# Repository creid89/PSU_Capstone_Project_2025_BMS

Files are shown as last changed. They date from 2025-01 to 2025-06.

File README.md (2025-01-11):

2025 PSU Senior Capstone Project

Battery Management System for PSU Student EPL (Engineering Prototyping Lab)

Members:
Cuauhtemoc Gomez Angeles <cuauh@pdx.edu>
Cody Reid <codreid@pdx.edu>
Fernando Custodio Calderon <fernan27@pdx.edu>
Tyler Tran <tytran@pdx.edu>
Daniel Anishchenko <danish2@pdx.edu>

Inudstry Sponsor: 
Edward Ivory <edivory@pdx.edu>

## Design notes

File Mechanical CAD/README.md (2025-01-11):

This folder contains the mechanical design files for the project. These files are created and maintained using CAD (Computer-Aided Design) software and include models, assemblies, drawings, and related documentation.

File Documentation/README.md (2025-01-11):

This folder contains all project-related documentation, including guides, reports, reference materials, and other supporting files. The purpose of this folder is to provide detailed information about the project, its design, implementation, and usage.

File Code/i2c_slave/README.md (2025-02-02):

Folder to store revisions of i2c_init.c and Cmake files

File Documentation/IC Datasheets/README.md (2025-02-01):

Datasheets for ICs to potentially integrate for current sensing and ADC

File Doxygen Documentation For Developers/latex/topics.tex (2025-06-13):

\doxysection{Topics}
Here is a list of all topics with brief descriptions\+:\begin{DoxyCompactList}
\item \contentsline{section}{EEPROM Storage Addresses}{\pageref{group___e_e_p_r_o_m___storage}}{}
\item \contentsline{section}{INA219 Sensor Instances}{\pageref{group___i_n_a219___instances}}{}
\item \contentsline{section}{Major System Control Flags}{\pageref{group___system___flags}}{}
\item \contentsline{section}{Timer and Configuration Flags}{\pageref{group___timer___flags}}{}
\item \contentsline{section}{INA219 and BQ25730 Variables}{\pageref{group___i_n_a___b_q___variables}}{}
\item \contentsline{section}{LTC2943 Scaling Factors and Constants}{\pageref{group___l_t_c2943___constants}}{}
\item \contentsline{section}{Cell Balancing Variables}{\pageref{group___balancer___variables}}{}
\item \contentsline{section}{System Return Variables}{\pageref{group___system___returns}}{}
\item \contentsline{section}{LTC2943 Configuration Parameters}{\pageref{group___l_t_c2943___config}}{}
\item \contentsline{section}{BQ25730 Charger Configuration Parameters}{\pageref{group___b_q25730___config}}{}
\item \contentsline{section}{Timing Control Variables}{\pageref{group___timing___variables}}{}
\item \contentsline{section}{I2C Communication Setup}{\pageref{group___i2_c___communication}}{}
\item \contentsline{section}{I2C Device Addresses}{\pageref{group___device___addresses}}{}
\item \contentsline{section}{LTC2943 Register Addresses}{\pageref{group___l_t_c2943___registers}}{}
\item \contentsline{section}{BQ25730 Register Addresses}{\pageref{group___b_q25730___registers}}{}
\item \contentsline{section}{LTC2943 Fuel Gauge Functions}{\pageref{group___l_t_c2943___functions}}{}
\item \contentsline{section}{BQ25730 Battery Charger Functions}{\pageref{group___b_q25730___functions}}{}
\end{DoxyCompactList}

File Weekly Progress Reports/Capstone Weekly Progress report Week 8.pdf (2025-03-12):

## Progress Report - Week 8 | Mar. 1 - Mar. 8, 2025

Group 6:
Cody Reid
Cuauhtemoc Gomez Angeles
Daniel Anishchenko
Tyler Tran
Fernando Custodio Calderon

Progress Discussion:
- Issues with actuating N-Channel Mosfet using Microcontroller’s GPIO Pins still persist for Cell Balancer.
- Transfer Switch in development; switching parameters are semi-operational. Currently on the 4th iteration of Transfer Switch.
- STM32 Peripheral mode prototyping successfully implemented
- STM32 reading from Qty. (1) INA260 and receiving messages over UART both on a timer interrupt basis.

Discussion Notes:
- New transfer switch design proposed by advisor, addition of nmos with the ideal diode will ensure switching using GPIO
- Don’t use linear supply
- start sending data back to the master system
- Investigations needed for battery chip to replace one of two load switches
- Found new battery chip: https://www.ti.com/product/BQ25713

Tasks at hand:
- integrate all 4 INAs
- Work on 4th iteration of advisor proposed load switch design
- Debug issues with GPIO controlled NMOS for battery balancer
- use a power supply and resistors to simulate charging
- generate a cell balancing algorithm
- Test charging behaviors of the 18650 Sodium cells
- Investigate BQ25713 for use in wall-end load switch

General Notes From Meeting:

Load Switch Operation
- M3 and M4 are load switches in a high-side configuration.
- To power the load, both transistors must be on.
- If only M4 is on, current still flows to the load through the body diode of M3, causing a 0.7V drop.
- The body diode is an intrinsic part of the MOSFET, like D1 and D2 in the circuit.

Battery Charging and Voltage Regulation

Connecting a 20V charger to a 12V battery:
- Current flows from the charger to the battery.
- The amount of current depends on how the charger regulates its voltage.

Understanding Current Flow:
- If the external power supply is 12V and the battery is 12V, little to no current flows.
- Increasing the charger voltage slightly (e.g., 12.1V) causes some current to flow, depending on internal resistances (battery, wiring, etc.).
- To control current, the charger uses a constant current supply, which regulates voltage to maintain a set charging current (e.g., 1A, 5A, 10A).

Charging Phases:
1. Constant Current Mode:
- The charger increases voltage until the target charging current is reached (e.g., 5A).
- The battery voltage gradually rises as it charges.
2. Constant Voltage Mode:
- Once the battery reaches its float voltage (e.g., 12.5V), the charger stops increasing voltage.
- Current gradually decreases as the battery approaches full charge.
- At full charge, current stabilizes at a low float value.

Charge Graph Behavior:
- Current rises sharply in constant current mode.
- As voltage reaches float level, current tapers off.
- The battery remains in a float state, maintaining its charge.

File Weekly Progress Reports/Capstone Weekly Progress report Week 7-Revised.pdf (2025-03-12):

## Progress Report - Week 7 | Feb. 22 - Mar. 1, 2025

Group 6:
Cody Reid
Cuauhtemoc Gomez Angeles
Daniel Anishchenko
Tyler Tran
Fernando Custodio Calderon

Progress Discussion:
- The Cell Balancing Circuit is operational, currently facing actuating N-Channel Mosfet to activate with the Microcontroller’s GPIO Pins.
- Transfer Switch in development; switching parameters are semi-operational. Currently on the 3rd iteration of Transfer Switch.
- Programming Notes:
○

Discussion Notes:
- Need to get the transfer switch working. Prototype is at hand, but no components to test at the moment.
- The load switch will be controlled by the transfer switch.
- Have a capacitor that when power is unplugged, and cap reaches zero, load switch is kicked from external control to load.
- When external power is plugged in, voltages go to both the load AND the batteries
- Sensor Transition:
- Moved from using the INA219 and ADS1115 to four INA260 sensors.
- The ADS1115 was inaccurate and could not reliably measure the voltages seen in a 4S battery pack.
- The INA260 provides all necessary measurements (voltage, current, and power) in a single package, simplifying the design.
- Microcontroller Update:
- Switched from the RP2350 to an STM32.
- Currently implementing UART communication between a controller and the STM32 for data transmission.
- Load Switching: Implementing an ideal diode to efficiently manage switching the load on and off from the battery supply.
- Power Management Discussion: Evaluating the use of a Charger IC to manage power when the system is plugged into an external source (e.g., wall outlet).

Tasks at hand:
- STM32 Peripheral mode prototyping
- Test and integrate transfer switch w/ balancing circuit.

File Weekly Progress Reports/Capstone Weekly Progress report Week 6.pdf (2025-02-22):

# Progress Report - Week 6 | Feb. 15 - 22, 2025

Group 6:
Cody Reid
Cuauhtemoc Gomez Angeles
Daniel Anishchenko
Tyler Tran
Fernando Custodio Calderon

Notes:
- We will use a thermistor for thermal regulation, ADC has extra pins so maybe multiple thermistors?
- Transfer switches; need to figure out if we want to use pmos or nmos. Leaning towards Pmos, explored BJT options
- Breakthrough made with passive cell balancing circuit, will need to integrate with transfer switch design
- Physical testing of transfer design needed, will be started within this week - in progress
- Transfer switch difficulties 2/18, MOSFETS burned, will need replacements on 2/19
- Test program will need to be made this week that allows transfer switch toggling using rp2350
- We managed to explode an INA219 module. Device fried (no seriously, RIP shunt resistor)
- Issues being faced with sensors INA219 - Mainly with getting it to handshake consistently
- Team managed to connect to the ADC and the Current meter, still working on dialing in calculations for the voltage and figuring out reference voltage best practices
- Battery housing being reprinted and will be picked up on Wednesday
- Wednesday Feb. 19 @4pm in person meeting w/ Andrew Greenburg at EPL
- Looking for 19V adc due to our current one not being able to handle the voltage
- Consider the use of the ina226 due to a higher power rating
- Use shunt resistors to mitigate power
- Consider the use of Ideal diodes for the transfer switch

Tasks at hand:
- Project Proposal - Still need legal part for IP As of Feb 15 - Will need to start giving pushback to speedup process
- Sensor Validation
- RP2350 Peripheral mode prototyping
- Passive battery balancing design
- Test and integrate transfer switch w/ balancing circuit
- Battery housing (3D printed) - DELAYED DUE TO SNOW - need to pickup

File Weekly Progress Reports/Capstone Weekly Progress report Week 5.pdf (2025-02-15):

# Progress Report - Week 5 | Feb. 8 - 15, 2025

Group 6:
Cody Reid
Cuauhtemoc Gomez Angeles
Daniel Anishchenko
Tyler Tran
Fernando Custodio Calderon

Notes:
- Progress slightly hampered this week due to midterms
- Wednesday Feb. 19 @4pm in person meeting w/ Andrew Greenburg at EPL
- Battery housing printed on Feb 12, however a reprint is needed due to quality issues. As of Feb 13, snow day has delayed pick up of 3d model
- Progress made in balancing circuit design and development of semi working prototype will be in progress from this Feb 15 onward to Feb 22.
- Current sensor module on both sides, we want sensing of both I/O
- Overvoltage goes to charge control voltage switch
- Undervoltage goes to control power output switch
- power output stage -> output switch
- Transfer switch - > Bypass Switch

Tasks at hand:

- Project Proposal - Still need legal part for IP As of Feb 15
- Sensor integration with I2C bus
- Sodium ion battery tests with balancing circuit
- Test and integrate transfer switch w/ balancing circuit
- Battery housing (3D printed) - DELAYED DUE TO SNOW

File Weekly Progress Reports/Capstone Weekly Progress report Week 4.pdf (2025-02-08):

# Progress Report - Week 4 | Feb. 1 - 8, 2025

Group 6:
Cody Reid
Cuauhtemoc Gomez Angeles
Daniel Anishchenko
Tyler Tran
Fernando Custodio Calderon

Notes:
- Difficulty have been encountered with RP2350 connections, we might decide to switch over to the rp2040
- We decided not to use ADC due to issues we found during experimentation with the board
- Met with advisor and sponsor on Feb 03 to discuss IP and the project proposal, in short, Ed will own the IP but we are free to use the design
- We will work on revising our level 1 block diagram
- Progress made on transfer switch design with this article. (https://www.powersystemsdesign.com/articles/application-of-power-mosfet-in-battery-management-charge-discharge-system/145/19032) Purpose of the transfer switch is to toggle between 1s, 2s, 3s, 4s.
- We will also switch to C++ on the arduino IDE - this decision is accepted by our advisor and sponsor
- We will schedule a meeting with Ed and/or staff of the epl to work with the PCB mill and laser cutter
- We will now use a 24V power supply instead of 12V

Tasks at hand:

- Project Proposal - Submit by Saturday 2/8 11:59 UPDATE: Need Legal IP statement from Andrew to be pasted
- I2C bus implementation
- Hardware and battery tests
- Transfer switch mosfet design
- Battery housing (3D printed)

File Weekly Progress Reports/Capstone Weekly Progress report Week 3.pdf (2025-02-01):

# Progress Report - Week 3 | Jan. 24 - Feb. 1, 2025

Group 6:
Cody Reid
Cuauhtemoc Gomez Angeles
Daniel Anishchenko
Tyler Tran
Fernando Custodio Calderon

Notes:
- Buy Power Supply (https://www.amazon.com/Adapter-Converter-Transformer-100-240V-Security/dp/B0BX2MYCV9)
- Get batteries from Ed
- Test functionality rp2350
- Validate hardware
- See if our battery data is in line with real world usage
- I2C slave config
- For architecture, choose gpio sensor package, battery management chip, or IO breakout/expansion board - will need to decide on this by the end of this week 2/1 -Update: We will do a component by component solution for this
- Rtas integration - decide after we choose architecture *Andrew suggests NOT to use it due to the added complexity
- straight C or circuitPython is recommended by Andrew
- Schedule a meeting to go over proposal on Friday 2pm Online
- Next week - Faculty Advisor meeting moved to Friday @3pm
- For development keep using ARDUINO To just get things to work and then eventually ditch Arduino and then go straight C. If we start with straight C, try to find libraries then for I 2C communication and all that kind of stuff.
- Faculty advisor needs to give input
So now is the time to share that with ED and with Andrew and they'll give comments and proposals and by the third we need both of their signatures saying that this is good to go
- 3 high-level architectures, The first one we just used the RP 2350 we might use a couple of its analog pins But for the most part we'd be using a management IC that we would then kind of tune to make it happy with sodium ion
- Second option
was we use some sort of IO expansion board because of the RP 2350 doesn't have a lot of analog pins And we'll basically kind of design our own BMS and software using that
- 3rd would be Maybe using some sort of IO expansion board Yeah, like a IO expansion board or something another sensor package or we could try and do it all Through the pins and sensors
- SUGGESTION from Andrew , use I2C and ADC, ADC that can handle the voltage of a 4 s-pack so up to 12 volts,
And so that way you don't have you don't have to worry about the crappy Picos analog and also shifting the analog voltage and or having dividers or anything that's like that might be able to get small I 2C package that can handle the voltage and then just you can just wire it straight into All 4 channels,(4 channels , cell 1,2,3,4)
- Andrew got scheduled to go to California Wednesday to Thursday he will try and call in but might not be able to make it wednesday of next week
- So we should schedule a different time
- Andrew wants us to to get 3S using a 12V battery for LI ION cuz alot of things will use that (3 should be a HIGH SHOULD)
- Ed wants the IP
He's thinking about selling it
We Might want to negotiate with him while andrew is there, and should be in the project proposal
●
- chat with Ed about setting up maybe like an accounting System or something for all the EPL stuff that we're gonna be grabbing
- Use Google spreadsheet for tracking the EPL stuff we take
- Power Supply Adapter (https://www.amazon.com/Adapter-Converter-Transformer-100-240V-Security/dp/B0BX2MYCV9)
- Next week 2:30pm Tuesday zoom meeting
- Next week 3pm Monday in person
- Adafruit ADS7830 8-channel w/ I2C - Add to buy list
- Instead of utilizing a BMS, we will make our own using a component by component solution

Tasks at hand:

- Project Proposal - will finish rough draft on Saturday, 1/25 and reviewed by our faculty advisor + sponsor to be submitted on Monday 2/3 for the final draft - UPDATE no feedback from Advisor & Sponsor as of Feb. 1st.
- Research research research Part 2- need to research more on the RP2350, This task will be for the whole team

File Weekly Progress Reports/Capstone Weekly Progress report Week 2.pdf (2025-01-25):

# Progress Report - Week 2 | Jan. 17-24, 2025

Group 6:
Cody Reid
Cuauhtemoc Gomez Angeles
Daniel Anishchenko
Tyler Tran
Fernando Custodio Calderon

Notes:

- Meeting with Ed on Wednesday 4:00-4:45pm
- Met after meeting with Ed to work on Project Proposal
- Battery data (found on google drive) has been updated with new data on Nimh
- Sodium ion will now be moved to should instead of must. This decision is confirmed by Ed, our sponsor. Edit: as of Friday January 24, we now have the decision canonized by our faculty advisor.
- Plan is to meet on Saturday to finalize the rough draft of the project proposal
- Andrew Greenburg is now assigned to us as our faculty advisor in 1/24
- RP2040 has arrived and testing and experimentation will commence as soon as possible
- We will explore the possibility of cannibalizing the Raspberry Pi Pico 2’s SOM for our own circuit
- Something that we have to consider in this project will be battery safety, which will be apparent when managing the Lithium batteries.
- In the meeting with our faculty advisor we have decided to assign a communications lead and team lead. Cody, who is our communication lead, will be in charge of anything that relates to the communication between the team and the sponsor. Daniel will be our team lead, who will ensure team organization and synergy. He will report any issues to our Faculty Advisor.
- We will also now meet with our faculty advisor on Wednesdays at 3:00 pm PST for a short 15-30 minute check-in. Make sure project logs/ progress reports are ready by then.

Tasks at hand:

- Project Proposal - will finish rough draft on Saturday, 1/25 and reviewed by our faculty advisor + sponsor to be submitted on Monday 1/26 for the final draft
- PDS - Worked slightly on this
- Research research research - need to research more on charge balance specifically passive balancing which is what Ed recommends. Also more research will have to be done for the system architecture.

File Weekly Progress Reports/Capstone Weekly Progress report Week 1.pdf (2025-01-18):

# Progress Report - Week 1 | Jan. 11-17, 2025

Group 6:
Cody Reid
Cuauhtemoc Gomez Angeles
Daniel Anishchenko
Tyler Tran
Fernando Custodio Calderon

Notes:

- Decided to meet twice a week:
- Wednesdays @ 1:45 for approximately 15 min
- Saturday 10am or 11am to 1pm
- Decided to use only Github for everything instead of using both google drive and git to simplify matters
- Met with Industry sponsor on Jan. 13, in summary we need to design a relatively inexpensive board that will be mainly for the Sodium ion 18650, the three others will come later (See Jan 13 meeting notes for more details)
- Chose a few Power management IC’s to work with, namely the TI BQ21061, TI BQ26221, and the Seiko S-8225A
- Need more material on Nickel Polymer batteries

Tasks at hand:

- Team Contract - Finish by the end of Saturday. Jan 18
- PDS - Start on this as soon as possible but might need to meet with Ed again
- Research research research - need to get a clearer picture of what we are going to create: need to figure out battery management system, battery charging system, and quirks with each given battery type

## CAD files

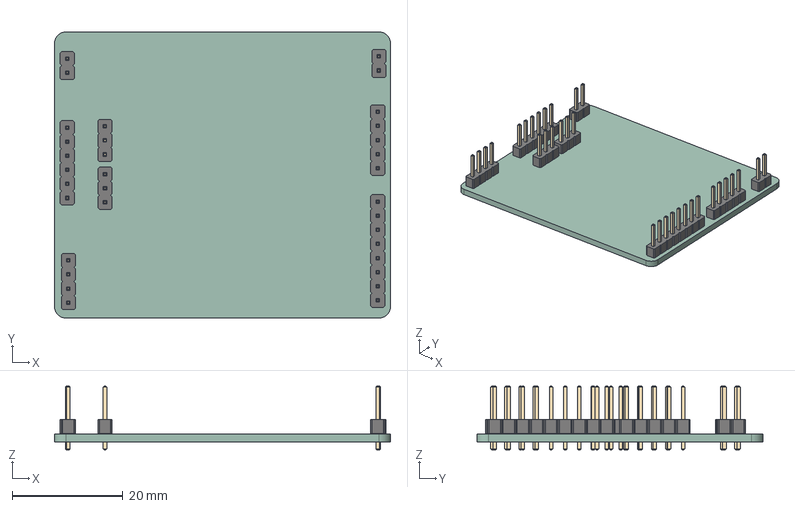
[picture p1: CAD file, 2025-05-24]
Board/Breakout/Breakout Board for BMS.step
60.6 x 51.6 x 11.5 mm
PinHeader_1x03_P2.54mm_Vertical x 2
PinHeader_1x04_P2.54mm_Vertical
PinHeader_1x02_P2.54mm_Vertical x 2
PinHeader_1x08_P2.54mm_Vertical
PinHeader_1x05_P2.54mm_Vertical
PinHeader_1x06_P2.54mm_Vertical
Breakout Board for BMS_PCB

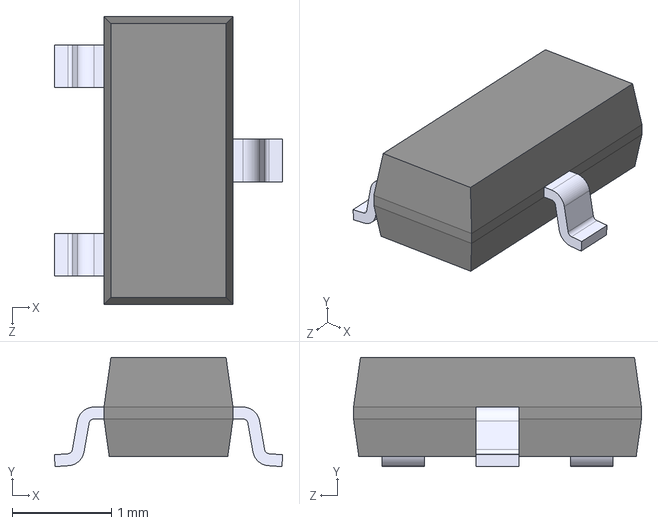
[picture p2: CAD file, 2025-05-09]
Board/KiCAD/Components/2N7002_215/2N7002P_215.step
2.30 x 1.10 x 2.90 mm

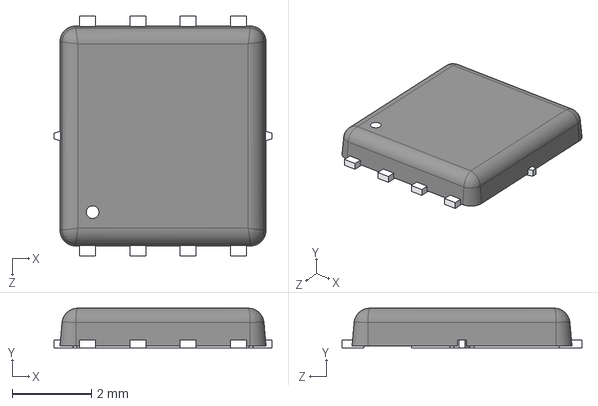
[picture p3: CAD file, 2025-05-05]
Board/KiCAD/Components/AON6407/AON6407.step
5.50 x 1.00 x 6.05 mm

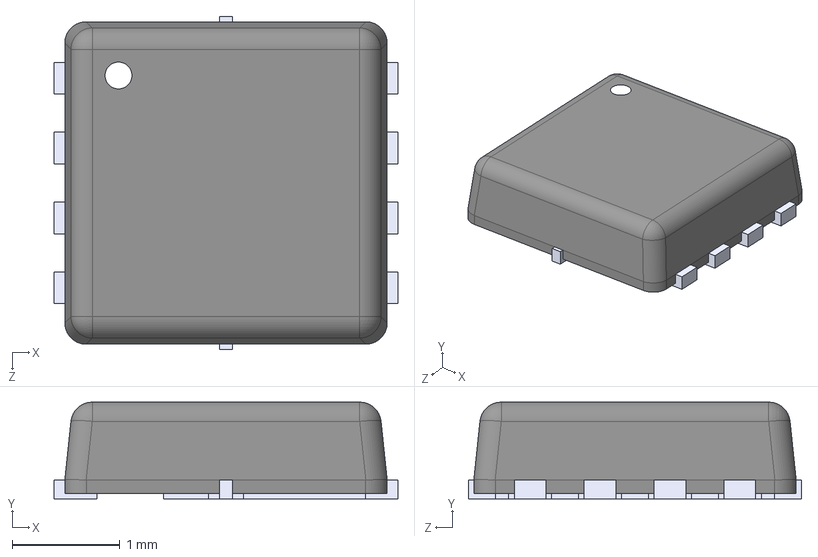
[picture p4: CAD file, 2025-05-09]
Board/KiCAD/Components/AON7407/AON7407.step
3.20 x 0.9 x 3.10 mm

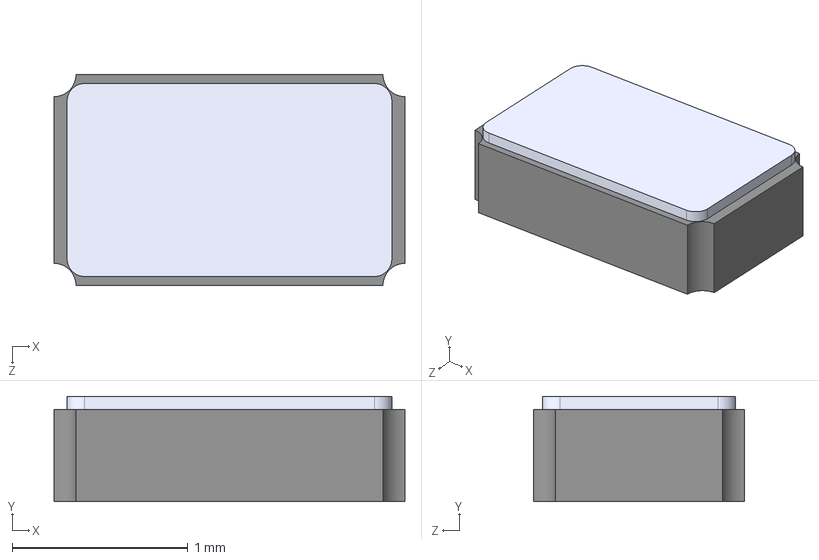
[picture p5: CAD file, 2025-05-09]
Board/KiCAD/Components/CM8V-T1A-32.768KHZ/CM8V-T1A-32.768KHZ-12.5PF-20PPM-TA-QA.step
2.00 x 0.6 x 1.20 mm

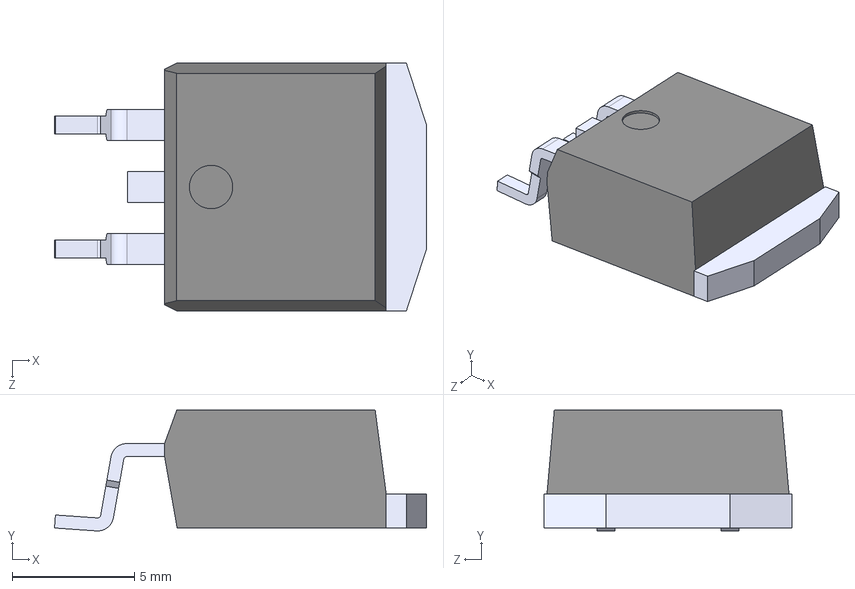
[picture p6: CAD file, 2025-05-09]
Board/KiCAD/Components/IRF9540NSTRLPBF/IRF9540NSTRLPBF.step
15.2 x 4.95 x 10.2 mm

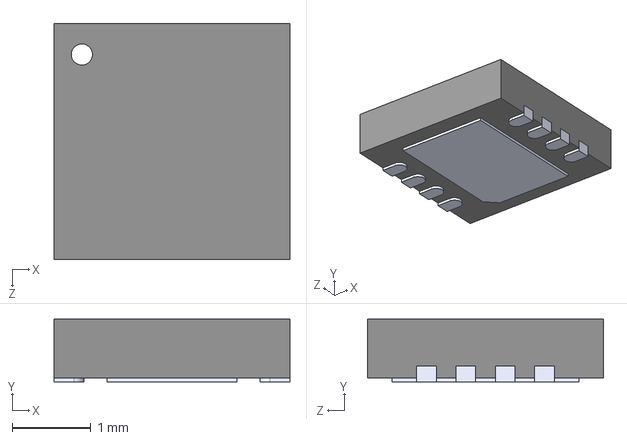
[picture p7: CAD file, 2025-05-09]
Board/KiCAD/Components/LTC2943/LTC2943CDD_PBF.step
3.00 x 0.8 x 3.00 mm

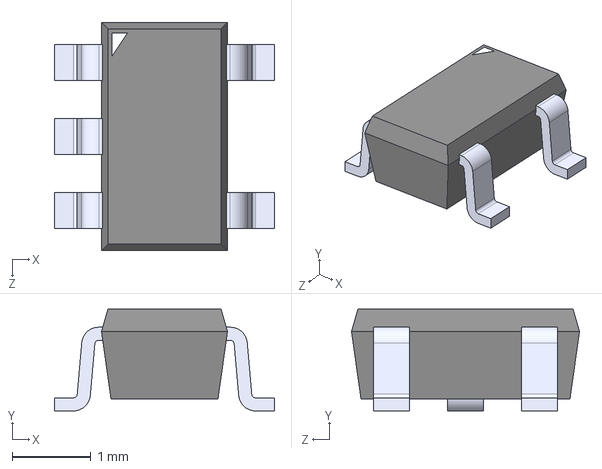
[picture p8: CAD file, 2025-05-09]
Board/KiCAD/Components/RT9193-32GB/RT9193-33GB.step
2.79 x 1.30 x 2.90 mm

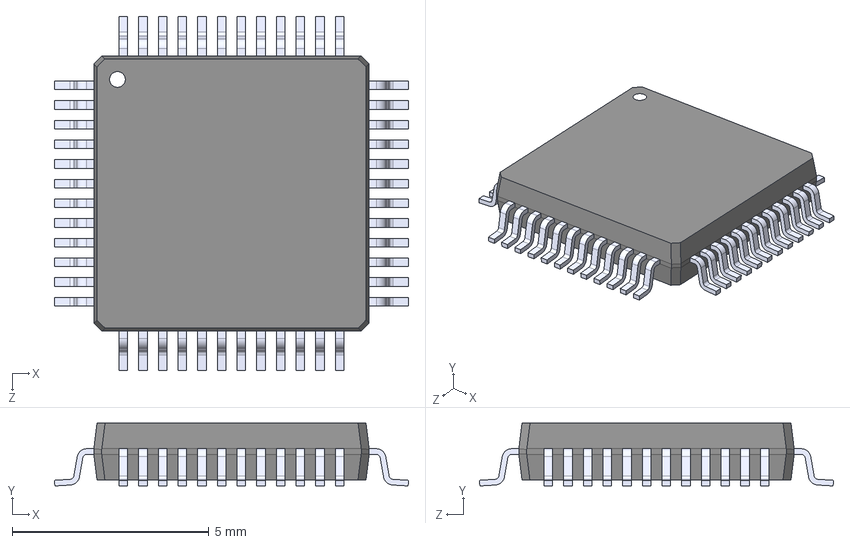
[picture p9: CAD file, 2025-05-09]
Board/KiCAD/Components/STM32F103C8T6/STM32F103C8T6.step
9.00 x 1.60 x 9.00 mm

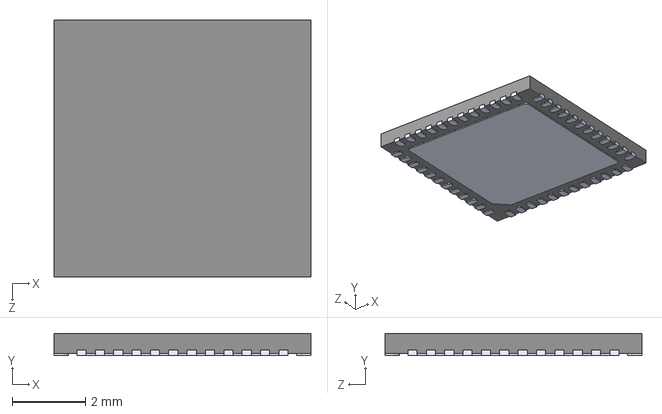
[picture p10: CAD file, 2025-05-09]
Board/KiCAD/Components/STM32F411CEU6/STM32F411CEU6.step
7.00 x 0.6 x 7.00 mm

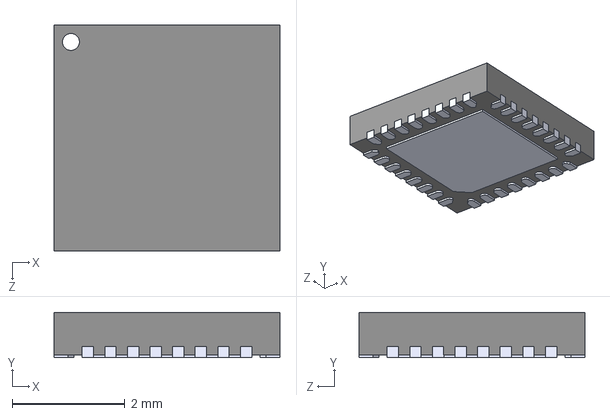
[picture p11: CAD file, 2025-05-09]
Board/KiCAD/Components/BQ25730RSNR/BQ25730RSNR.step
4.00 x 0.8 x 4.00 mm

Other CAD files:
Board/KiCAD/Components/AON7408/AON7408.step
Board/Breakout/Breakout Board for BMS.stl

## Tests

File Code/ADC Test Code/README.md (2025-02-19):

Folder to store code for testing the ADC

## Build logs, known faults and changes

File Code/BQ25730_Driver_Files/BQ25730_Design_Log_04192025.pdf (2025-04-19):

# BQ25730 Driver Development Log

### Developer

Cody Reid

### Project

Universal Battery Management System (BMS) Controller

### Component

BQ25730 Buck-Boost Battery Charger Controller

### Date Range

Ongoing (Latest Update: April 19, 2025)

### 1. Introduction

This document summarizes the design, implementation, testing, and ongoing development of a custom driver written in Arduino C++ for the BQ25730 battery charger IC. This driver is part of a broader Universal BMS Controller project, which aims to provide flexible and programmable charging logic for a wide range of battery chemistries and form factors.

The BQ25730 is a highly integrated buck-boost battery charge controller from Texas Instruments. It supports 1- to 5-cell battery configurations, input voltages from 3.5V to 26V, and charge/discharge currents up to 10A. The IC supports I2C/SMBus communication, allowing full configuration and monitoring by a host microcontroller.

### 2. Project Goals

- Establish reliable communication with BQ25730 using I2C
- Implement a modular and testable driver to manage battery charge parameters
- Enable charging across a wide range of conditions with system-level safety
- Ensure reusability for different cell configurations and battery types

### 3. Hardware Setup

- I2C Interface: Verified BQ25730 at 7-bit address 0x6B

-EVM: BMS5051 REV A

- MCU: STM32F103C8T6 ARM STM32
- Power Source: Bench power supply (12V–24V range)

- Battery: Sodium Ion 18650 3.0V 1.3Ah 3.90Wh 10C Rechargeable Battery 4S pack (used for test configuration)

### 4. Functional Overview

The firmware performs the following:

1. I2C Bus Initialization
2. Device Presence Check using Device ID register
3. Charger Configuration:
- Charge Voltage
- Charge Current
- Input Voltage Limit (VINDPM)
- Input Current Limit
- Minimum System Voltage (VSYS_MIN)
4. ADC Activation
5. Charging Enable/Disable Control
6. Fault Detection and I2C Auto-Recovery
7. Debug Printouts of Register Values

### 5. Code Design Decisions

- Modular function design for each configuration register
- I2C reliability enhancement via polling and auto-reset
- Delays added to prevent register write collisions
- ADC activated with one-shot mode
- Periodic re-write of charge settings to maintain charger state
- Serial printout of all registers for debugging

### 6. Charging Logic Summary

Battery Charging Phases:

Pre-Charge: Battery < 3V, limits current to 384 mA

Fast Charge (LDO): 3.0V < Battery < 3.6V, limited to 2 A

Full Fast Charge: Battery > 3.6V, full speed charging

### 7. Register Programming Examples

- Charge Voltage (0x04): (voltage / 0.008) << 3 → 16V = 0x3F00
- Charge Current (0x02): (current / 0.128) << 6 → 1A = 0x0200
- Input Voltage (0x0A): ((Vin - 3.2) / 0.064) << 6 → 12V = 0x1E00
- Input Current (0x0E): (mA / 50) << 8 → 2.1A = 0x2A00
- VSYS_MIN (0x0C): (voltage * 10) << 8 → 13.3V = 0x5300

### 8. Observations and Issues

- ADC values stop updating after charging ends
- VIN behavior during OTG not confirmed

### 9. Conclusion

This log captures the iterative development of the BQ25730 driver for a flexible BMS platform. The driver has reached a stable stage for configuring key charging parameters and monitoring battery behavior. Future development will focus on diagnostics, energy efficiency, and broader battery compatibility.

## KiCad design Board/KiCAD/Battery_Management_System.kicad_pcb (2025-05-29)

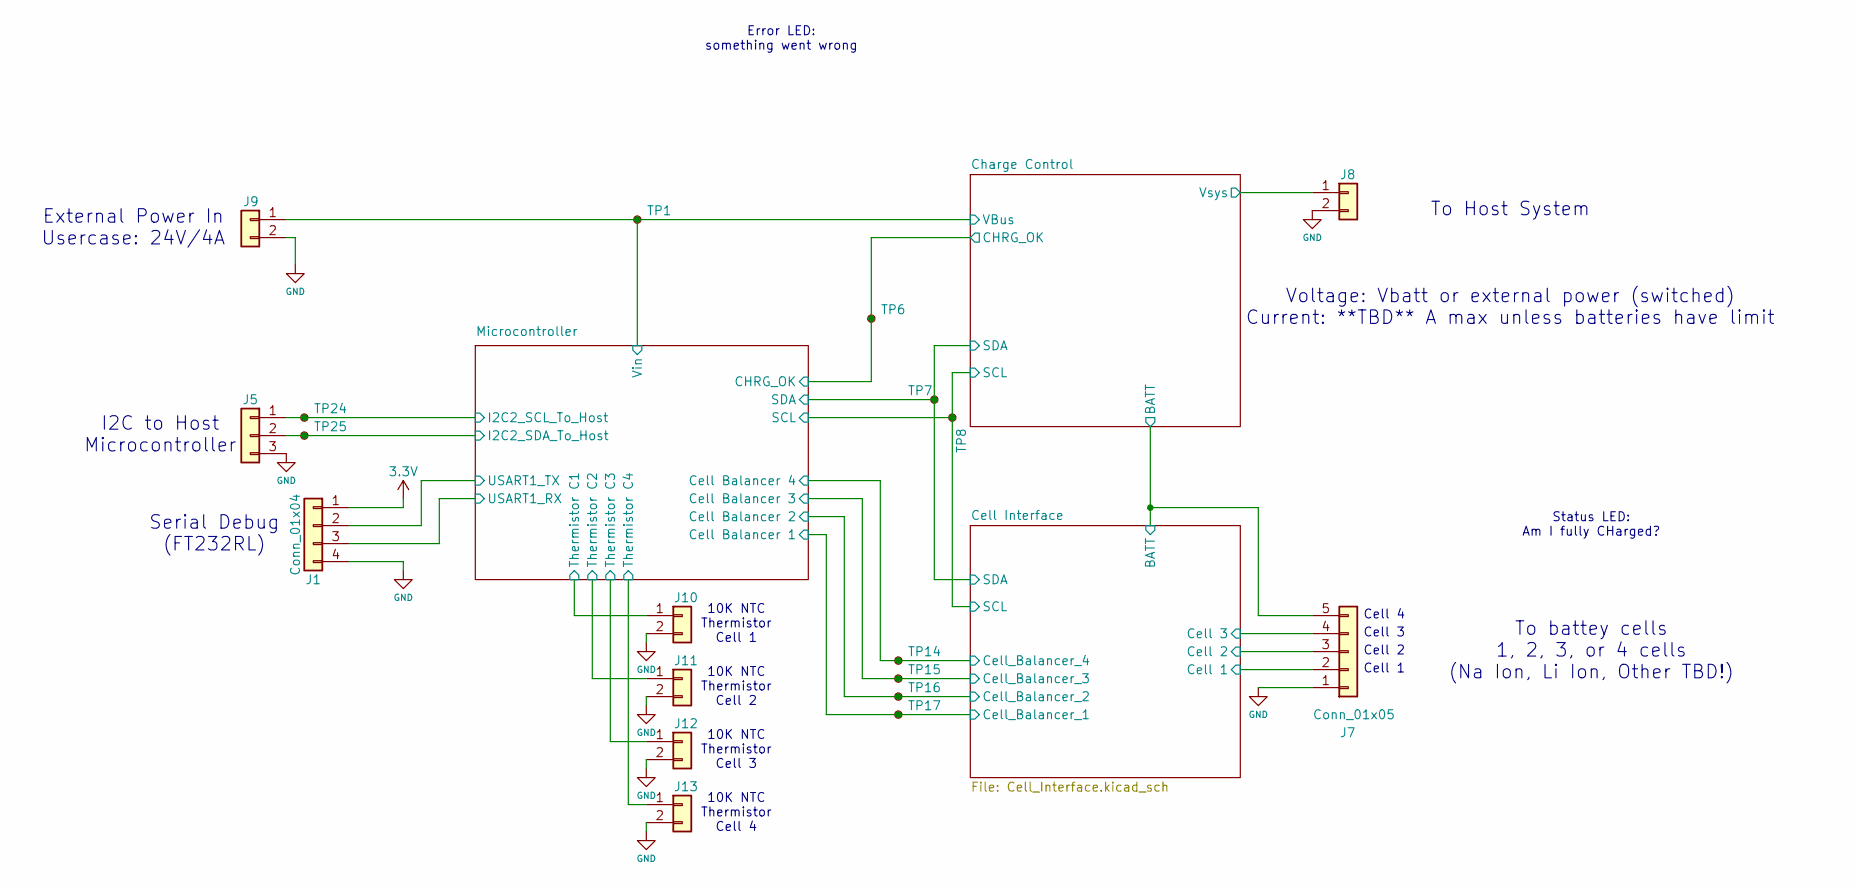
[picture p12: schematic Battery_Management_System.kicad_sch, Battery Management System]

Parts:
J1: Conn_01x04; PinHeader_1x04_P2.54mm_Vertical
J5: Conn_01x03; PinHeader_1x03_P2.54mm_Vertical; MPN 732-5316-ND
J7: Conn_01x05; PinHeader_1x05_P2.54mm_Vertical; MPN 732-5318-ND
J8, J9, J10, J11, J12, J13: Conn_01x02; PinHeader_1x02_P2.54mm_Vertical; MPN 5-146285-2-ND
TP1, TP6, TP7, TP8, TP14, TP15, TP16, TP17, TP24, TP25: TestPoint_Small; TestPoint_Pad_1.0x1.0mm

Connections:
3.3V: J1.1; also elsewhere on the board
/Cell Interface/BATT: J7.5; also elsewhere on the board
/Cell Interface/Cell 1: J7.2; also elsewhere on the board
/Cell Interface/Cell 2: J7.3; also elsewhere on the board
/Cell Interface/Cell 3: J7.4; also elsewhere on the board
/Cell Interface/Cell_Balancer_1: TP17.1; also elsewhere on the board
/Cell Interface/Cell_Balancer_2: TP16.1; also elsewhere on the board
/Cell Interface/Cell_Balancer_3: TP15.1; also elsewhere on the board
/Cell Interface/Cell_Balancer_4: TP14.1; also elsewhere on the board
/Cell Interface/SCL: TP8.1; also elsewhere on the board
/Cell Interface/SDA: TP7.1; also elsewhere on the board
/Charge Control/CHRG_OK: TP6.1; also elsewhere on the board
/Charge Control/VBus: J9.1, TP1.1; also elsewhere on the board
/Charge Control/Vsys: J8.1; also elsewhere on the board
/Microcontroller/I2C2_SCL_To_Host: J5.1, TP24.1; also elsewhere on the board
/Microcontroller/I2C2_SDA_To_Host: J5.2, TP25.1; also elsewhere on the board
/Microcontroller/Thermistor C1: J10.1; also elsewhere on the board
/Microcontroller/Thermistor C2: J11.1; also elsewhere on the board
/Microcontroller/Thermistor C3: J12.1; also elsewhere on the board
/Microcontroller/Thermistor C4: J13.1; also elsewhere on the board
/Microcontroller/USART1_RX: J1.3; also elsewhere on the board
/Microcontroller/USART1_TX: J1.2; also elsewhere on the board
GND: J1.4, J5.3, J7.1, J8.2, J9.2, J10.2, J11.2, J12.2, J13.2; also elsewhere on the board

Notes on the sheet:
Cell 3
I2C to Host Microcontroller
10K NTC Thermistor Cell 1
Cell 4
10K NTC Thermistor Cell 3
10K NTC Thermistor Cell 2
Error LED: something went wrong
To battey cells 1, 2, 3, or 4 cells (Na Ion, Li Ion, Other TBD!)
Cell 2
To Host System Voltage: Vbatt or external power (switched) Current: **TBD** A max unless batteries have limit
Serial Debug (FT232RL)
External Power In Usercase: 24V/4A
Cell 1
Status LED: Am I fully CHarged?
10K NTC Thermistor Cell 4

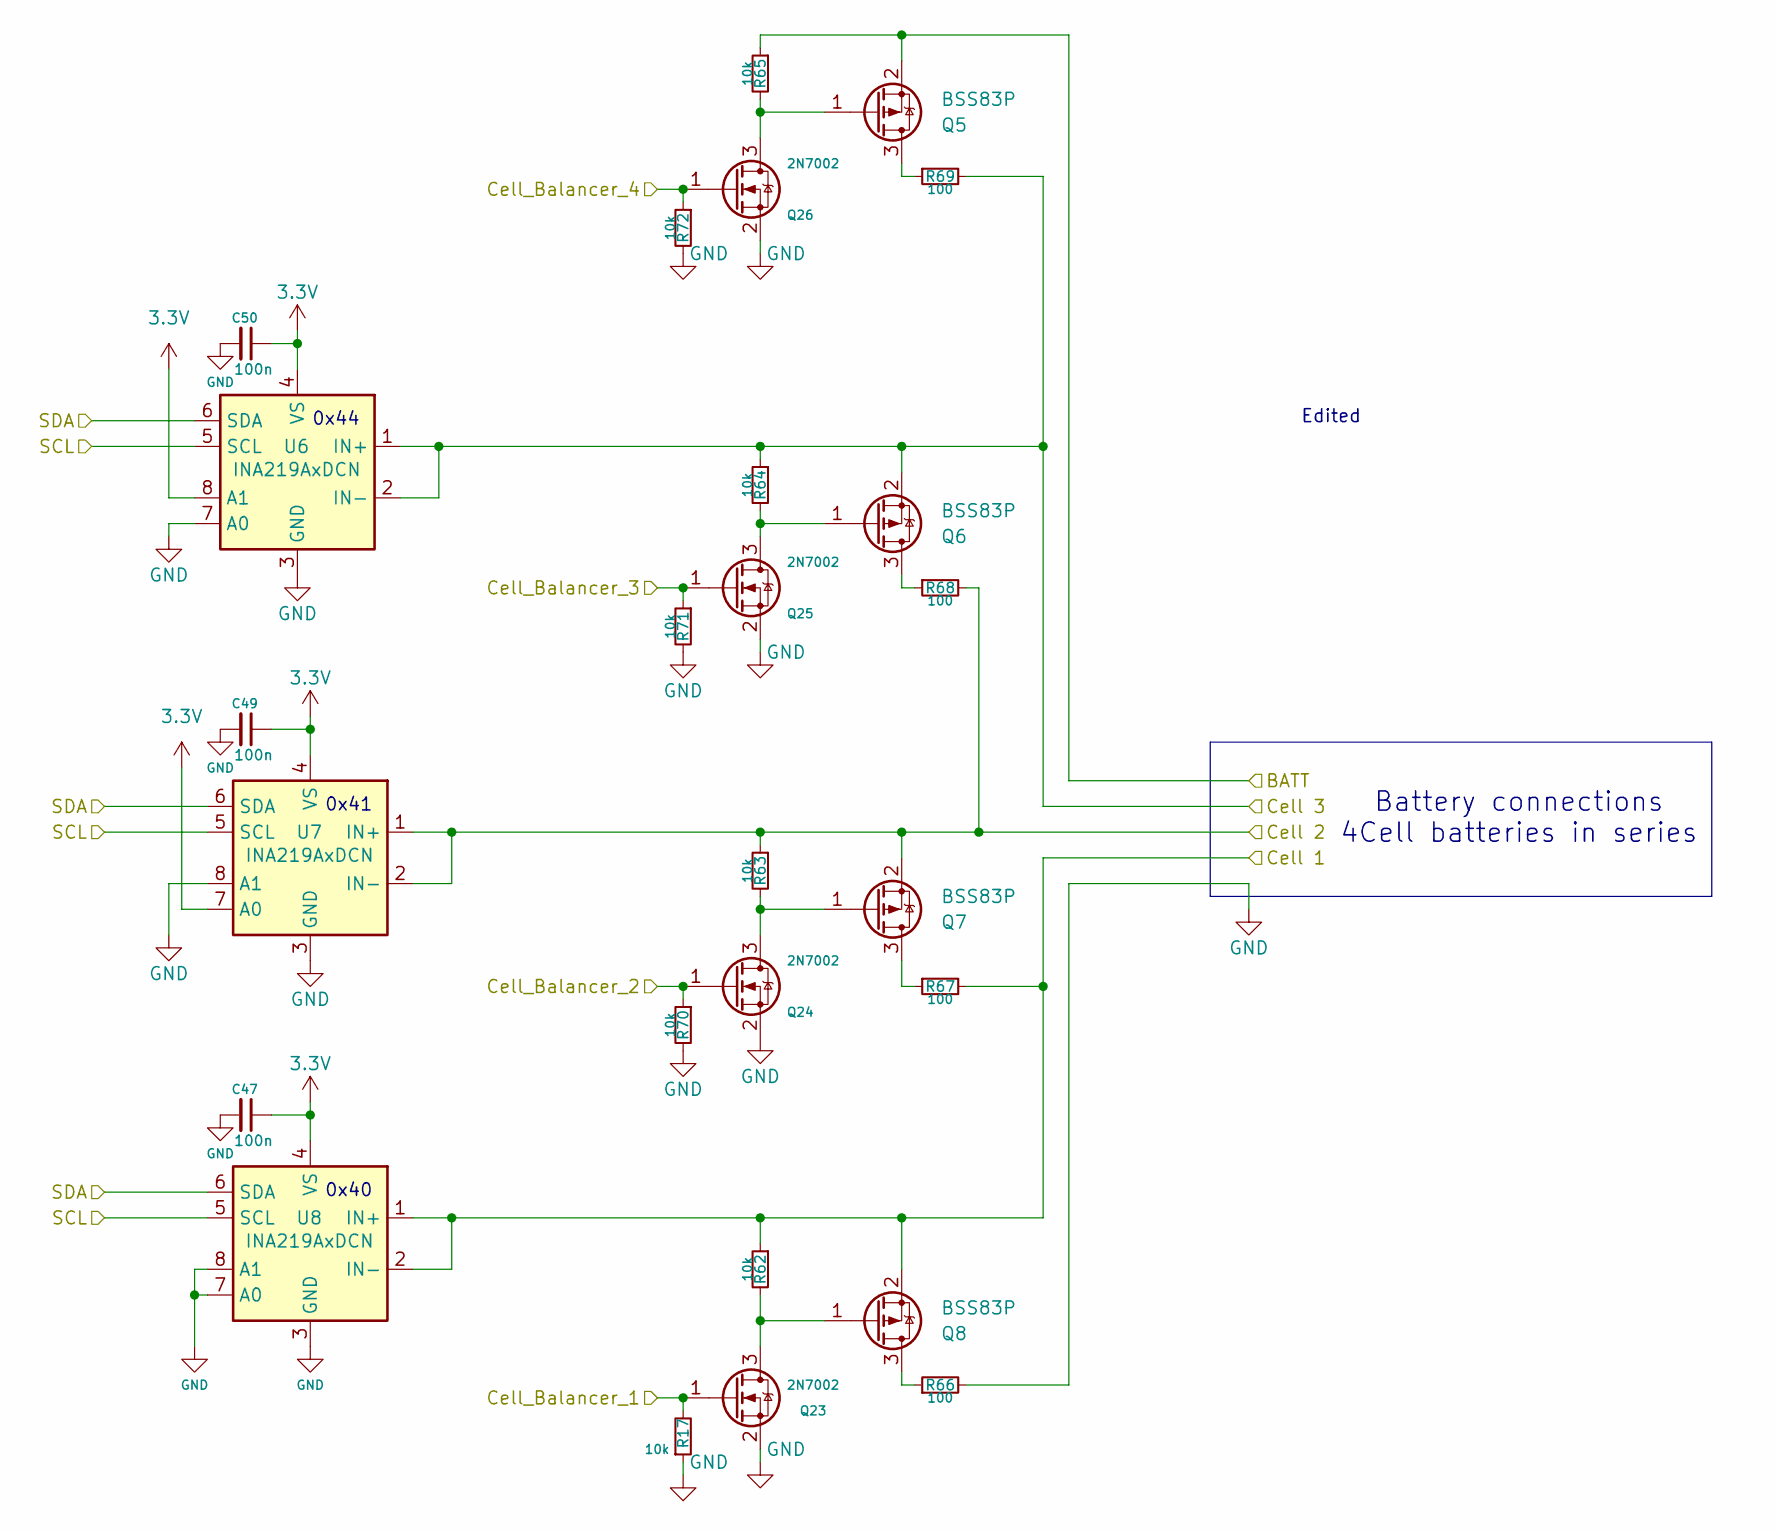
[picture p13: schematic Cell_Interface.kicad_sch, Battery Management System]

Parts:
C47, C49, C50: 100n; C_0603_1608Metric; MPN 1276-6720-1-ND
Q5, Q6, Q7, Q8: BSS83P; SOT-23; MPN BSS83PH6327XTSA1CT-ND
Q23, Q24, Q25, Q26: 2N7002; SOT-23; MPN 2N7002NCT-ND
R17, R62, R63, R64, R65, R70, R71, R72: 10k; R_0603_1608Metric; MPN RMCF0603FT10K0CT-ND
R66, R67, R68, R69: 100; R_1206_3216Metric; MPN RNCF1206TKY100RCT-ND
U6, U7, U8: INA219AxDCN; SOT-23-8; MPN 296-23770-1-ND

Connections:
3.3V: C47.1, C49.1, C50.1, U6.4 (VS), U6.8 (A1), U7.4 (VS), U7.7 (A0), U8.4 (VS); also elsewhere on the board
/Cell Interface/BATT: Q5.2 (S), R65.1; also elsewhere on the board
/Cell Interface/Cell 1: Q8.2 (S), R62.1, R67.2, U8.1 (IN+), U8.2 (IN-); also elsewhere on the board
/Cell Interface/Cell 2: Q7.2 (S), R63.1, R68.2, U7.1 (IN+), U7.2 (IN-); also elsewhere on the board
/Cell Interface/Cell 3: Q6.2 (S), R64.1, R69.2, U6.1 (IN+), U6.2 (IN-); also elsewhere on the board
/Cell Interface/Cell_Balancer_1: Q23.1 (G), R17.2; also elsewhere on the board
/Cell Interface/Cell_Balancer_2: Q24.1 (G), R70.1; also elsewhere on the board
/Cell Interface/Cell_Balancer_3: Q25.1 (G), R71.1; also elsewhere on the board
/Cell Interface/Cell_Balancer_4: Q26.1 (G), R72.1; also elsewhere on the board
/Cell Interface/SCL: U6.5 (SCL), U7.5 (SCL), U8.5 (SCL); also elsewhere on the board
/Cell Interface/SDA: U6.6 (SDA), U7.6 (SDA), U8.6 (SDA); also elsewhere on the board
GND: C47.2, C49.2, C50.2, Q23.2 (S), Q24.2 (S), Q25.2 (S), Q26.2 (S), R17.1, R66.2, R70.2, R71.2, R72.2, U6.3 (GND), U6.7 (A0), U7.3 (GND), U7.8 (A1), U8.3 (GND), U8.7 (A0), U8.8 (A1); also elsewhere on the board
unnamed: Q5.3 (D), R69.1
unnamed: Q6.3 (D), R68.1
unnamed: Q7.3 (D), R67.1
unnamed: Q8.3 (D), R66.1
unnamed: Q8.1 (G), Q23.3 (D), R62.2
unnamed: Q7.1 (G), Q24.3 (D), R63.2
unnamed: Q6.1 (G), Q25.3 (D), R64.2
unnamed: Q5.1 (G), Q26.3 (D), R65.2

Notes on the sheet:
0x44
Battery connections 4Cell batteries in series
Edited
0x40
0x41

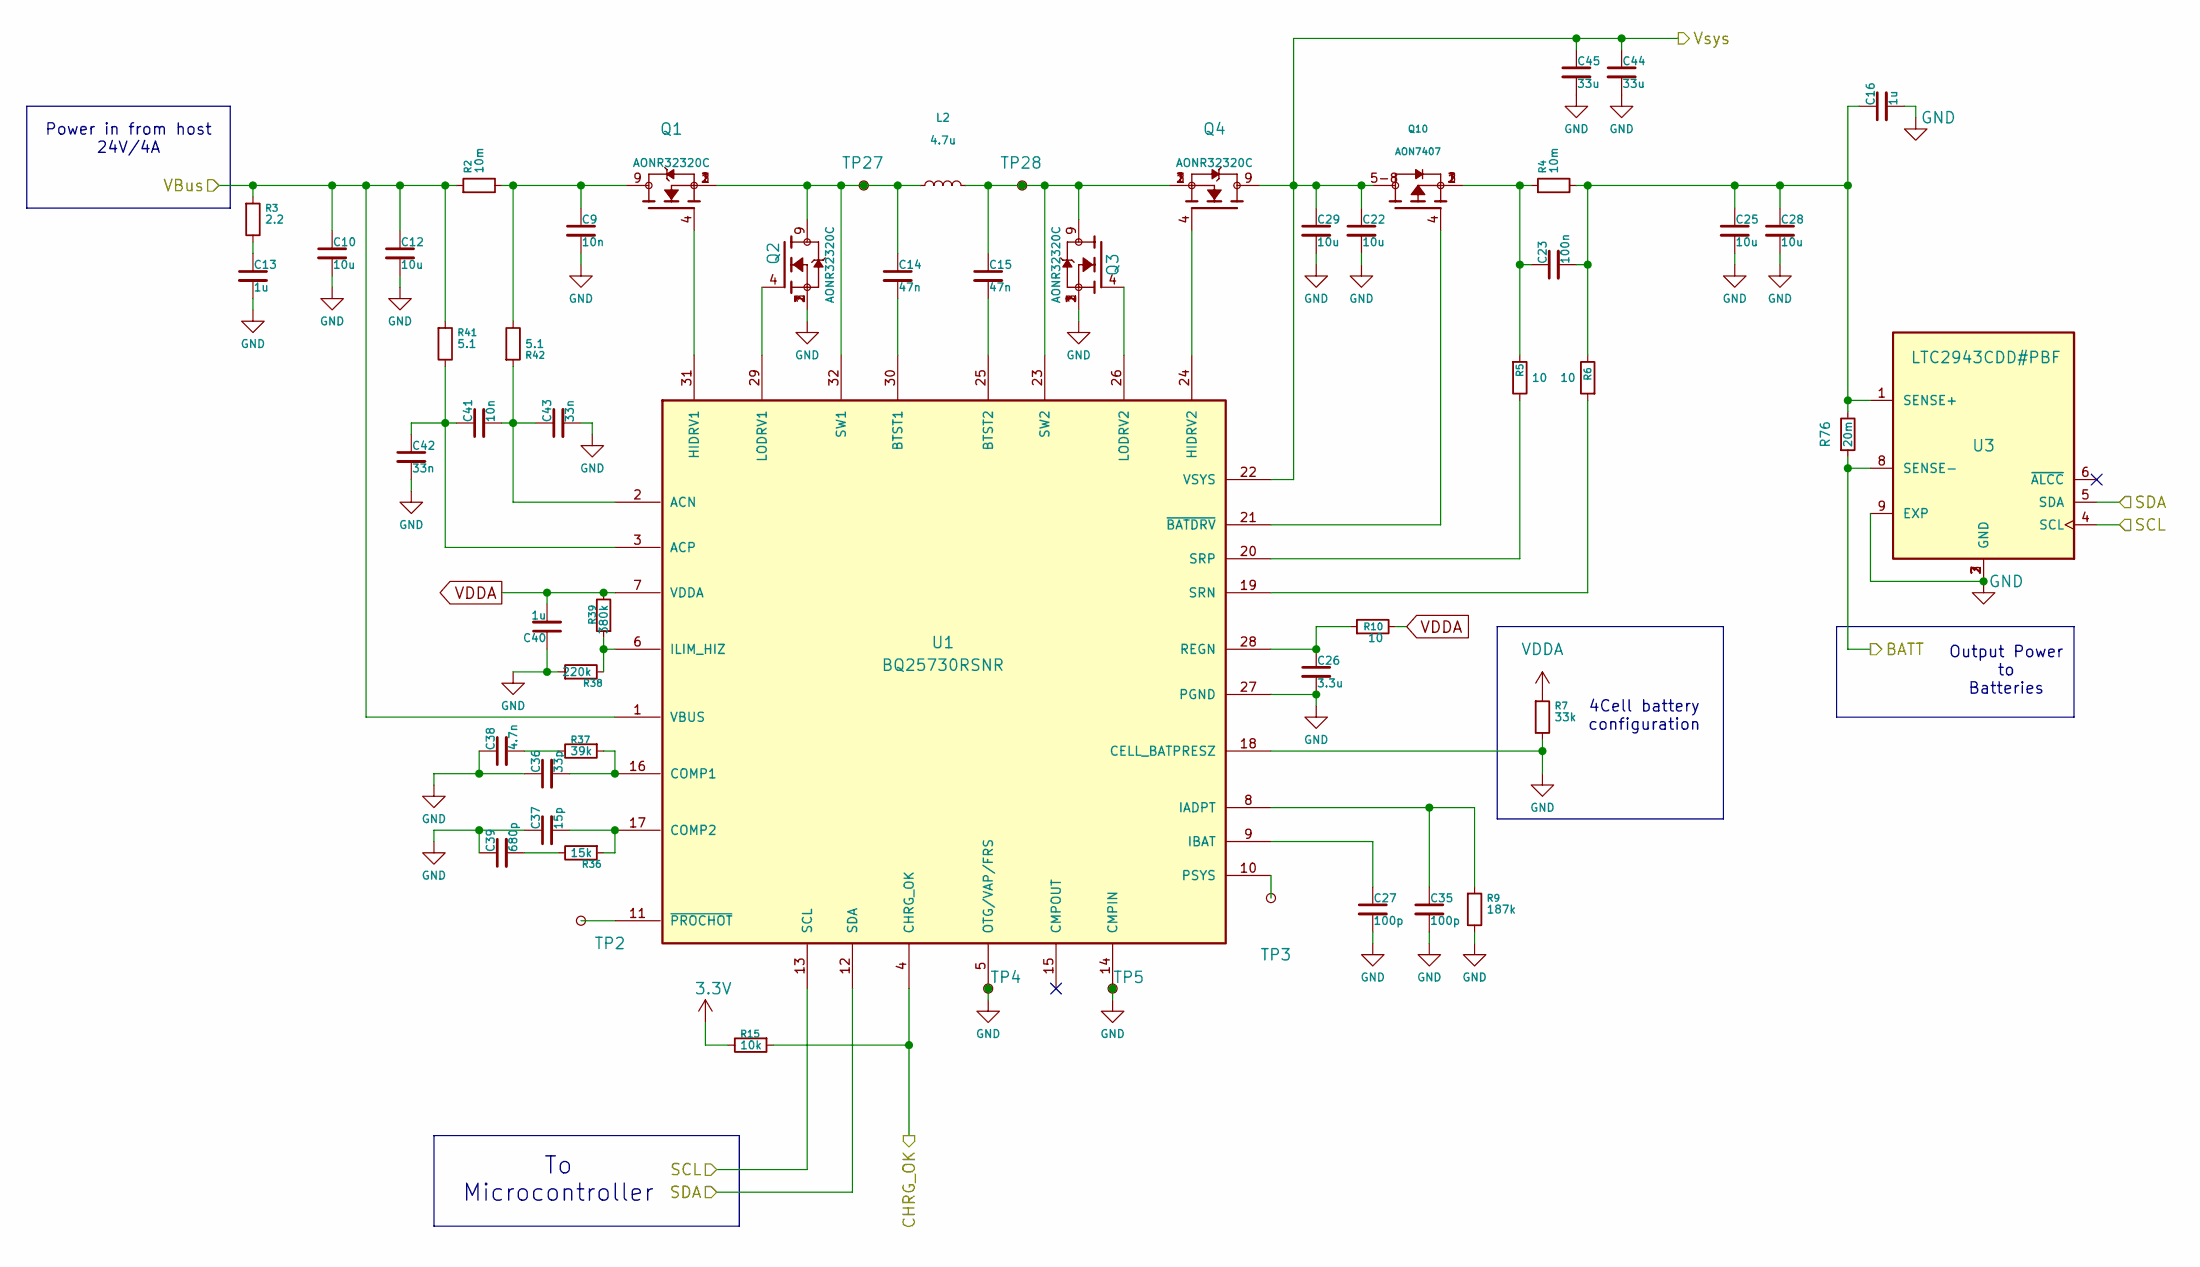
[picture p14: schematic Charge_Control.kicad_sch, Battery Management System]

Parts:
C9, C41: 10n; C_0603_1608Metric; MPN 490-3194-1-ND
C10, C12, C22, C25, C28, C29: 10u; C_1206_3216Metric; MPN 1276-1804-1-ND
C13, C16, C40: 1u; C_0603_1608Metric; MPN 1276-1946-1-ND
C14, C15: 47n; C_0603_1608Metric; MPN 490-4934-1-ND
C23: 100n; C_0603_1608Metric; MPN 1276-6720-1-ND
C26: 3.3u; C_0603_1608Metric; MPN 1276-1892-1-ND
C27, C35: 100p; C_0603_1608Metric; MPN 490-1427-1-ND
C36: 33p; C_0603_1608Metric; MPN 490-1415-1-ND
C37: 15p; C_0603_1608Metric; MPN 478-600S150JT250XT4KCT-ND
C38: 4.7n; C_0603_1608Metric; MPN 445-6912-1-ND
C39: 680p; C_0603_1608Metric; MPN 399-C0603C681F5GACTUCT-ND
C42, C43: 33n; C_0603_1608Metric; MPN 490-8025-1-ND
C44, C45: 33u; C_1206_3216Metric; MPN 490-1415-1-ND
L2: 4.7u; L_10.4x10.4_H4.8; MPN 495-1805-1-ND
Q1, Q2, Q3, Q4: AONR32320C; TRANS_AON7408; MPN 785-AONR32320CCT-ND
Q10: AON7407; TRANS_AON7407; MPN 785-1306-1-ND
R2, R4: 10m; R_1206_3216Metric; MPN CSR1206FK10L0CT-ND
R3: 2.2; R_1206_3216Metric
R5, R6, R10: 10; R_0603_1608Metric; MPN RMCF0603FT10R0CT-ND
R7: 33k; R_0603_1608Metric; MPN RMCF0603FT33K0CT-ND
R9: 187k; R_0603_1608Metric; MPN RMCF0603FT187KCT-ND
R15: 10k; R_0603_1608Metric; MPN RMCF0603FT10K0CT-ND
R36: 15k; R_0603_1608Metric; MPN RMCF0603FT15K0CT-ND
R37: 39k; R_0603_1608Metric; MPN RMCF0603JT39K0CT-ND
R38: 220k; R_0603_1608Metric; MPN RMCF0603FT220KCT-ND
R39: 380k; R_0603_1608Metric; MPN RMCF0603FT383KCT-ND
R41, R42: 5.1; R_0603_1608Metric; MPN RMCF0603FT5R10CT-ND
R76: 20m; R_1206_3216Metric; MPN CSR1206FK20L0CT-ND
TP2, TP3, TP4, TP5, TP27, TP28: TestPoint_Small; TestPoint_Pad_1.0x1.0mm
U1: BQ25730RSNR; IC_BQ25730RSNR; MPN BQ25730RSNR
U3: LTC2943CDD#PBF; MLF-8-1EP_3x3mm_P0.65mm_EP1.55x2.3mm; MPN LTC2943CDD#PBF

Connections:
3.3V: R15.2; also elsewhere on the board
/Cell Interface/BATT: R76.1, U3.8 (SENSE-); also elsewhere on the board
/Cell Interface/SCL: U1.13 (SCL), U3.4 (SCL); also elsewhere on the board
/Cell Interface/SDA: U1.12 (SDA), U3.5 (SDA); also elsewhere on the board
/Charge Control/CHRG_OK: R15.1, U1.4 (CHRG_OK); also elsewhere on the board
/Charge Control/VBus: C10.1, C12.1, R2.1, R3.1, R41.1, U1.1 (VBUS); also elsewhere on the board
/Charge Control/Vsys: C22.1, C29.1, C44.1, C45.1, Q4.9, Q10.5-8, U1.22 (VSYS); also elsewhere on the board
GND: C9.2, C10.2, C12.2, C13.2, C16.2, C22.2, C25.2, C26.2, C27.2, C28.2, C29.2, C35.2, C36.1, C37.1, C38.1, C39.1, C40.1, C42.2, C43.2, C44.2, C45.2, Q2.1, Q2.2, Q2.3, Q3.1, Q3.2, Q3.3, R7.2, R9.2, R38.1, TP4.1, TP5.1, U1.5 (OTG/VAP/FRS), U1.14 (CMPIN), U1.18 (CELL_BATPRESZ), U1.27 (PGND), U1.33, U1.34, U1.35, U1.36, U1.37, U1.38, U1.39, U1.40, U1.41, U1.42, U3.2 (GND), U3.3 (GND), U3.7 (GND), U3.9 (EXP); also elsewhere on the board
unnamed: C9.1, Q1.9, R2.2, R42.2
unnamed: C13.1, R3.2
unnamed: C23.1, Q10.1, Q10.2, Q10.3, R4.1, R5.1
unnamed: C38.2, R37.2
unnamed: C39.2, R36.2
unnamed: C41.2, C43.1, R42.1, U1.2 (ACN)
unnamed: C41.1, C42.1, R41.2, U1.3 (ACP)
unnamed: C14.2, U1.30 (BTST1)
unnamed: C15.2, U1.25 (BTST2)
unnamed: C36.2, R37.1, U1.16 (COMP1)
unnamed: C37.2, R36.1, U1.17 (COMP2)
unnamed: Q1.4, U1.31 (HIDRV1)
unnamed: Q4.4, U1.24 (HIDRV2)
unnamed: C35.1, R9.1, U1.8 (IADPT)
unnamed: C27.1, U1.9 (IBAT)
unnamed: R38.2, R39.1, U1.6 (ILIM_HIZ)
unnamed: Q2.4, U1.29 (LODRV1)
unnamed: Q3.4, U1.26 (LODRV2)
unnamed: TP3.1, U1.10 (PSYS)
unnamed: C26.1, R10.1, U1.28 (REGN)
unnamed: R6.1, U1.19 (SRN)
unnamed: R5.2, U1.20 (SRP)
unnamed: C14.1, L2.1, Q1.1, Q1.2, Q1.3, Q2.9, TP27.1, U1.32 (SW1)
unnamed: C15.1, L2.2, Q3.9, Q4.1, Q4.2, Q4.3, TP28.1, U1.23 (SW2)
unnamed: Q10.4, U1.21 (~BATDRV)
unnamed: TP2.1, U1.11 (~PROCHOT)
unnamed: C16.1, C23.2, C25.1, C28.1, R4.2, R6.2, R76.2, U3.1 (SENSE+)
VDDA: C40.2, R7.1, R10.2, R39.2, U1.7 (VDDA)

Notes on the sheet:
4Cell battery configuration
To Microcontroller
Power in from host 24V/4A
Output Power to Batteries

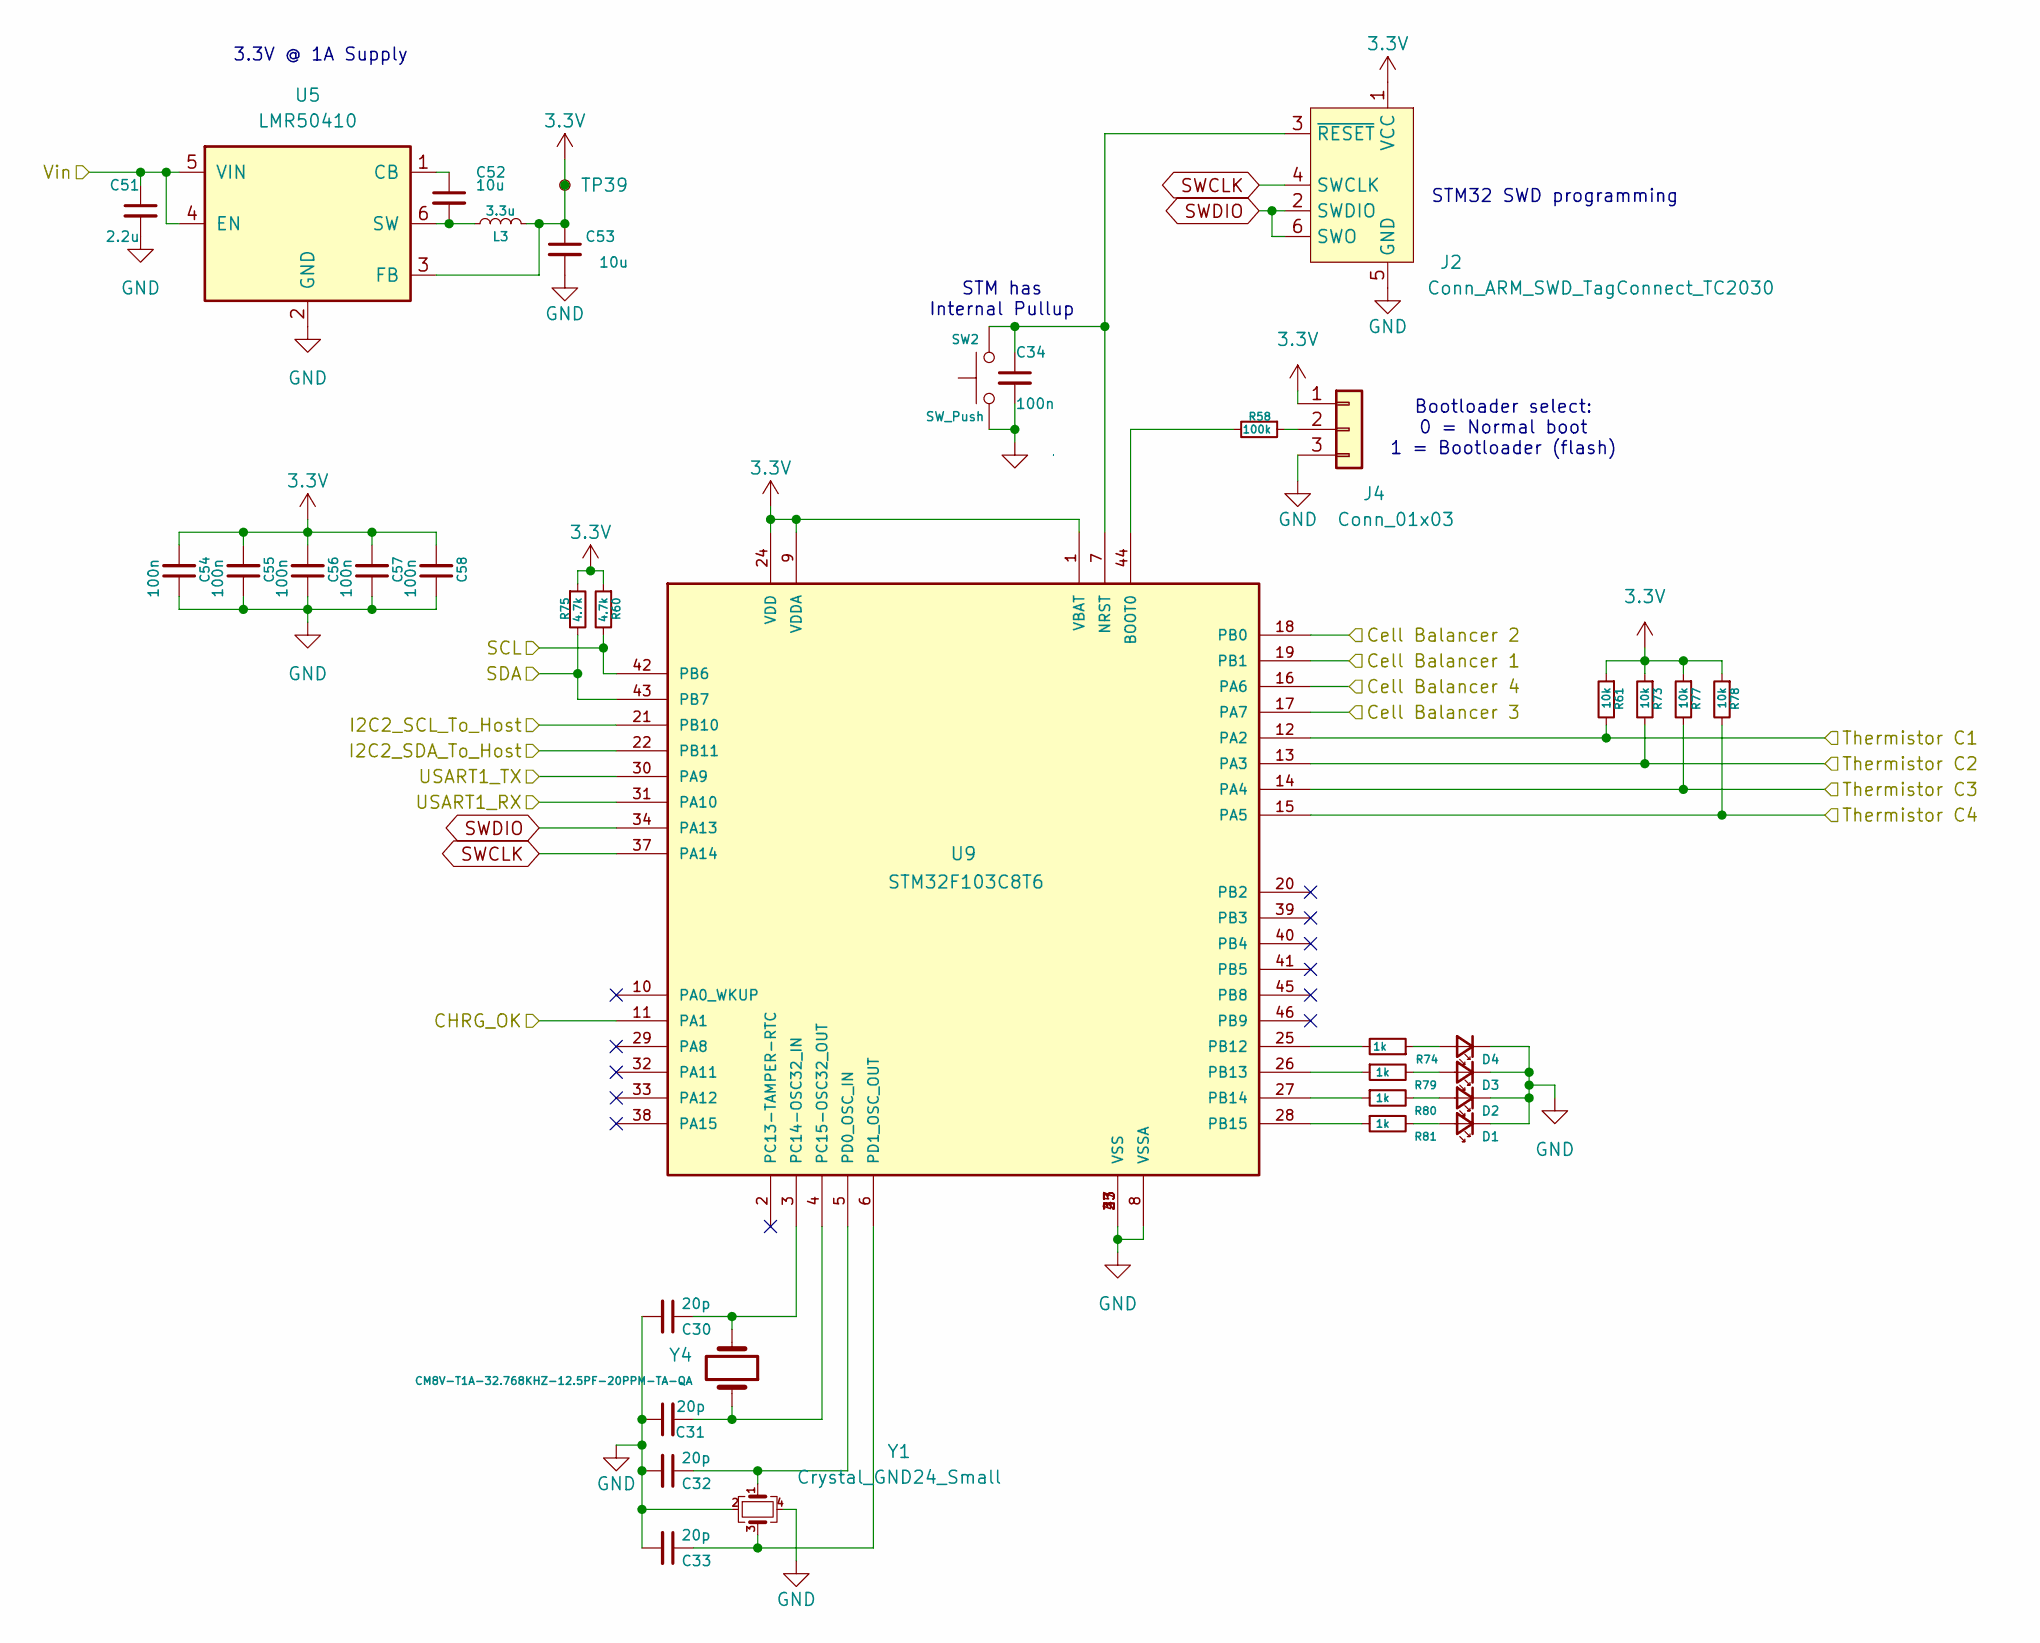
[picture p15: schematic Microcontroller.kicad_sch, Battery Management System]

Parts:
C30, C31, C32, C33: 20p; C_0603_1608Metric; MPN 478-600S200FT250XT4KCT-ND
C34, C54, C55, C56, C57, C58: 100n; C_0603_1608Metric; MPN 1276-6720-1-ND
C51: 2.2u; C_1206_3216Metric; MPN 587-2909-1-ND
C52, C53: 10u; C_1206_3216Metric; MPN 1276-1804-1-ND
D1, D2, D3, D4: LED_Small; LED_0603_1608Metric
J2: Conn_ARM_SWD_TagConnect_TC2030; Tag-Connect_TC2030-IDC-NL_2x03_P1.27mm_Vertical; MPN TC2030-CTX-ND
J4: Conn_01x03; PinHeader_1x03_P2.54mm_Vertical; MPN 732-5316-ND
L3: 3.3u; L_1008_2520Metric_Pad1.43x2.20mm_HandSolder; MPN 587-3227-1-ND
R58: 100k; R_0603_1608Metric; MPN RMCF0603FT100KCT-ND
R60, R75: 4.7k; R_0603_1608Metric; MPN RMCF0603FT4K70CT-ND
R61, R73, R77, R78: 10k; R_0603_1608Metric; MPN RMCF0603FT10K0CT-ND
R74, R79, R80, R81: 1k; R_0603_1608Metric; MPN RMCF0603FT10K0CT-ND
SW2: SW_Push; SW_Push_SPST_NO_Alps_SKRK; MPN CKN12220-1-ND
TP39: TestPoint_Small; TestPoint_Pad_1.0x1.0mm
U5: LMR50410; SOT-23-6; MPN 296-LMR50410XFDBVRCT-ND
U9: STM32F103C8T6; QFP50P900X900X160-48N; MPN STM32F103C8T6
Y1: Crystal_GND24_Small; Crystal_SMD_TXC_7M-4Pin_3.2x2.5mm; MPN 7V-8.000MDDQ-T
Y4: CM8V-T1A-32.768KHZ-12.5PF-20PPM-TA-QA; XTAL_CM8V-T1A-32.768KHZ-12.5PF-20PPM-TA-QA; MPN CM8V-T1A-32.768KHZ-12.5PF-20PPM-TA-QA

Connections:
3.3V: C53.1, C54.2, C55.2, C56.2, C57.2, C58.2, J2.1 (VCC), J4.1, L3.2, R60.1, R61.1, R73.1, R75.1, R77.1, R78.1, TP39.1, U5.3 (FB), U9.1 (VBAT), U9.9 (VDDA), U9.24 (VDD), U9.36 (VDD), U9.48 (VDD); also elsewhere on the board
/Cell Interface/Cell_Balancer_1: U9.19 (PB1); also elsewhere on the board
/Cell Interface/Cell_Balancer_2: U9.18 (PB0); also elsewhere on the board
/Cell Interface/Cell_Balancer_3: U9.17 (PA7); also elsewhere on the board
/Cell Interface/Cell_Balancer_4: U9.16 (PA6); also elsewhere on the board
/Cell Interface/SCL: R60.2, U9.42 (PB6); also elsewhere on the board
/Cell Interface/SDA: R75.2, U9.43 (PB7); also elsewhere on the board
/Charge Control/CHRG_OK: U9.11 (PA1); also elsewhere on the board
/Charge Control/VBus: C51.1, U5.4 (EN), U5.5 (VIN); also elsewhere on the board
/Microcontroller/I2C2_SCL_To_Host: U9.21 (PB10); also elsewhere on the board
/Microcontroller/I2C2_SDA_To_Host: U9.22 (PB11); also elsewhere on the board
/Microcontroller/Thermistor C1: R61.2, U9.12 (PA2); also elsewhere on the board
/Microcontroller/Thermistor C2: R73.2, U9.13 (PA3); also elsewhere on the board
/Microcontroller/Thermistor C3: R77.2, U9.14 (PA4); also elsewhere on the board
/Microcontroller/Thermistor C4: R78.2, U9.15 (PA5); also elsewhere on the board
/Microcontroller/USART1_RX: U9.31 (PA10); also elsewhere on the board
/Microcontroller/USART1_TX: U9.30 (PA9); also elsewhere on the board
GND: C30.2, C31.1, C32.2, C33.2, C34.2, C51.2, C53.2, C54.1, C55.1, C56.1, C57.1, C58.1, D1.1 (K), D2.1 (K), D3.1 (K), D4.1 (K), J2.5 (GND), J4.3, SW2.1, U5.2 (GND), U9.8 (VSSA), U9.23 (VSS), U9.35 (VSS), U9.47 (VSS), Y1.2, Y1.4; also elsewhere on the board
unnamed: D1.2 (A), R81.2
unnamed: D2.2 (A), R80.2
unnamed: D3.2 (A), R79.2
unnamed: D4.2 (A), R74.1
unnamed: C34.1, J2.3 (~RESET), SW2.2, U9.7 (NRST)
unnamed: J4.2, R58.1
unnamed: C52.1, U5.1 (CB)
unnamed: C52.2, L3.1, U5.6 (SW)
unnamed: R58.2, U9.44 (BOOT0)
unnamed: R74.2, U9.25 (PB12)
unnamed: R79.1, U9.26 (PB13)
unnamed: R80.1, U9.27 (PB14)
unnamed: R81.1, U9.28 (PB15)
unnamed: C30.1, U9.3 (PC14-OSC32_IN), Y4.2
unnamed: C31.2, U9.4 (PC15-OSC32_OUT), Y4.1
unnamed: C32.1, U9.5 (PD0_OSC_IN), Y1.1
unnamed: C33.1, U9.6 (PD1_OSC_OUT), Y1.3
SWCLK: J2.4 (SWCLK), U9.37 (PA14)
SWDIO: J2.2 (SWDIO), J2.6 (SWO), U9.34 (PA13)

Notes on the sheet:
STM32 SWD programming
3.3V @ 1A Supply
Bootloader select: 0 = Normal boot 1 = Bootloader (flash)
STM has Internal Pullup

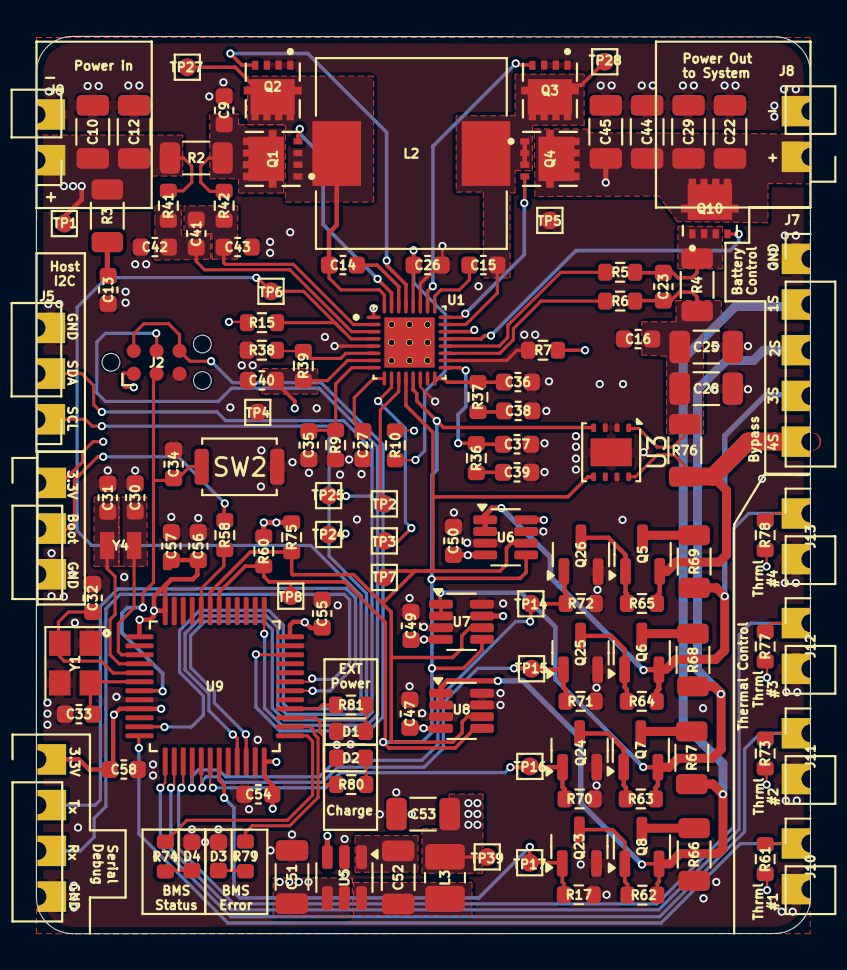
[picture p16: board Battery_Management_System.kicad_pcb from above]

Board: 4 copper layers, 43.0 x 49.8 mm, 137 parts (0 on the bottom side), 78 nets.

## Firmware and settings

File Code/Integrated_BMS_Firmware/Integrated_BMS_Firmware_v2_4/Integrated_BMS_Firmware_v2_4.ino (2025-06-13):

//Integrated BMS Firmware V2_4
//Sodium & Lithium ION BMS

//Include wire for I2C
#include <Wire.h>
//Includes for INA
#include <Adafruit_INA219.h>
//include for interrupts
#include <HardwareSerial.h>
#include <STM32TimerInterrupt.h>
#include "stm32f1xx.h"
#include <EEPROM.h>

//EEPROM Storage for Init System Values Passed by Controller uC
#define EEPROM_ADDR_1  0                                       // float 1
#define EEPROM_ADDR_2  (EEPROM_ADDR_1 + (2*sizeof(float)))         // float 2
#define EEPROM_ADDR_3  (EEPROM_ADDR_2 + (2*sizeof(float)))        // float 3
#define EEPROM_ADDR_4  (EEPROM_ADDR_3 + (2*sizeof(float)))        // float 4
#define EEPROM_ADDR_5  (EEPROM_ADDR_4 + (2*sizeof(float)))         // float 5
#define EEPROM_ADDR_6  (EEPROM_ADDR_5 + (2*sizeof(float)))         // float 6
#define EEPROM_ADDR_7  (EEPROM_ADDR_6 + (2*sizeof(float)))         // float 7
#define EEPROM_ADDR_8  (EEPROM_ADDR_7 + (2*sizeof(float)))         // float 8
#define EEPROM_ADDR_9  (EEPROM_ADDR_8 + (2*sizeof(float)))         // float 9
#define EEPROM_TOTAL_LENGTH (9 * (2*sizeof(float)))              // Total length for 8 floats

////////////////////////////////////////////////////////////////
// Create instances for each ina219 sensor
Adafruit_INA219 ina219_0x40(0x40);
Adafruit_INA219 ina219_0x41(0x41);
Adafruit_INA219 ina219_0x44(0x44);

//Major system flags
volatile bool CHARGING = false;
String serialCmdBuffer = "";    // accumulator for incoming chars for Charge control
volatile bool CHARGE_ON_PLUGIN = true;  // when true, charging auto‑starts on plugin
volatile bool STOPCHARGING = false;
volatile bool KILLLOAD = false;
volatile bool PLUGGEDIN = false;
volatile bool OVERHEAT = false;
volatile bool ERRORFLG = false;

//Timer Flags
volatile bool EEPROM_LOADED = false;
float EEPROM_CONFIG_FLAG;
volatile bool CONFIGURED = false;

int configstatus = 0;
int ConfigStatusFromMaster;
// Create a timer instance using TIM2 (adjust if needed)
STM32Timer ITimer2(TIM2);

// Timer ISR: set flags for sensor and serial update
void onTimerISR() {
  //TEST_FLAG = true;
}


//INA219/260 & BQ25730 vars
float INA_0x40_VOLTAGE = 0.0;
float INA_0x41_VOLTAGE = 0.0;
float INA_0x44_VOLTAGE = 0.0;
float CELL1_VOLTAGE_LTC2943 = 0.00;
float CELL1_VOLTAGE = 0.00;
float CELL2_VOLTAGE = 0.00;
float CELL3_VOLTAGE = 0.00;
float CELL4_VOLTAGE = 0.00;

// 3.3V / 2 = 1.65V --> scaled to 12-bit ADC: (1.65 / 3.3) * 4095 ≈ 2047
const int THERMISTER_THRESHOLD = 2047;

//LTC scaling factors
//resistance value for LTC2943
float resistor = .1;
const float LTC2943_CHARGE_lsb = 0.34E-3;
const float LTC2943_VOLTAGE_lsb = 1.44E-3;
const float LTC2943_CURRENT_lsb = 29.3E-6;
const float LTC2943_TEMPERATURE_lsb = 0.25;
const float LTC2943_FULLSCALE_VOLTAGE = 23.6;
const float LTC2943_FULLSCALE_CURRENT = 60E-3;
const float LTC2943_FULLSCALE_TEMPERATURE = 510;
float prescaler = 4096;

//Balancer Declarations
float CellMaxCutOffV; //need from user --> Done
float CellFullChargeV = CellMaxCutOffV - 0.1;
float CellMinCutOffV; //need from user --> Done

//vars for returns to main system
float PackVoltage = 0;
float current = 0;
float tempC = 0;
float charge_mAh = 0;
float real_charge_mAh = 0;

//LTC2943 Sense scaling Configuration parameters
float Pack_stock_capacity = 5200; //mA (2600*4 = 10400) //need from user --> Done
// Sense resistor in Ohms
const float RSENSE = 0.1f;

//CONTROL register prescaler setting (bits B[5:3] = 0b111 → M = 16384)
const float LTC2943_PRESCALER = 16384.0f;

//qLSB in mAh/count, per datasheet p.15:
//qLSB = 0.340 mAh × (50 mΩ / RSENSE) × (M / 4096)
const float QLSB = 0.340f * (50e-3f / RSENSE) * (LTC2943_PRESCALER / 4096.0f);

int numOfCells = 4;

//BQ25730 Configuration parameters
float ChargeVoltageValue=18;         // Charging target voltage - Later Change to --> float ChargeVoltageValue  = (numOfCells * CellMaxCutOffV) + 1;
float VsysMinValue;                 // Minimum system voltage
float inputVoltageValue;            // Input voltage limit (used for VINDPM)
float chargeCurrentValue=1;           // Battery charging current (in amps)
float inputCurrentLimitValue = 1;    // Input current limit (in milliamps) - based on supply/adapter limit

unsigned long lastCheck1 = 0;
const unsigned long I2CcheckInterval = 5000;

unsigned long lastCheck2 = 0;
const unsigned long registerUpdateInterval = 2500;

//////////////////////////////////////////////////////////////////////

//Define Slave Address of STM32 for controller comms
float responseData = 0.0;
TwoWire myI2C2(PB11, PB10);
#define SLAVE_ADDRESS 0x58

//Adress for LTC2943
#define LTC2943_ADDR 0x64  // 7-bit I2C address
//Adress for BQ25730
#define BQ25730_ADDR 0x6B  // 7-bit I2C address

// LTC2943 Register Addresses
#define REG_STATUS     0x00
#define REG_CONTROL    0x01
#define REG_ACC_CHARGE_MSB 0x02
#define REG_VOLTAGE_MSB    0x08
#define REG_CURRENT_MSB    0x0E
#define REG_TEMPERATURE_MSB 0x14

// BQ25730 Register addresses
#define ChargeOption0   0x00
#define ChargeCurrent   0x02
#define ChargeVoltage   0x04
#define OTGVoltage      0x06
#define OTGCurrent      0x08
#define InputVoltage    0x0A
#define VSYS_MIN        0x0C
#define IIN_HOST        0x0E
#define ChargerStatus   0x20
#define ProchotStatus   0x22
#define IIN_DPM         0x24
#define AADCVBUS_PSYS   0x26
#define ADCIBAT         0x28
#define ADCIINCMPIN     0x2A
#define ADCVSYSVBAT     0x2C
#define MANUFACTURER_ID 0x2E
#define DEVICE_ID       0x2F
#define ChargeOption1   0x30
#define ChargeOption2   0x32
#define ChargeOption3   0x34
#define ProchotOption0  0x36
#define ProchotOption1  0x38
#define ADCOption       0x3A
#define ChargeOption4   0x3C
#define Vmin_Active_Protection 0x3E
//////////////////////////////////////////////////////////////////////

void softwareReset() {
  NVIC_SystemReset();
}

//LTC Functions 
//write to LTC2943 register over I2C
void write_LTC2943_Register(uint8_t reg, uint8_t value) {
  Wire.beginTransmission(LTC2943_ADDR);
  Wire.write(reg);
  Wire.write(value);
  Wire.endTransmission();
}

//Reqest register and return register contents over I2C
uint16_t Read_LTC2943_Register(uint8_t reg) {
  Wire.beginTransmission(LTC2943_ADDR);
  Wire.write(reg);
  Wire.endTransmission(false);
  Wire.requestFrom(LTC2943_ADDR, (uint8_t)2);
  if (Wire.available() < 2) {
    Serial.println("I2C read failed");
    return 0;
  }
  uint16_t value = Wire.read() << 8;
  value |= Wire.read();
  return value;
}
//Functions to Modularly Reqest info from Fuel Guage
float Request_Voltage_LTC2943(){
  uint16_t vRaw = Read_LTC2943_Register(REG_VOLTAGE_MSB);
  // Voltage (16-bit, 23.6V full-scale)
  float LTCvoltage = 23.6 * vRaw / 65535.0;
  return LTCvoltage;
}

float Request_Current_LTC2943(){
  // Current (12-bit, ±60mV full scale, offset binary)
  uint16_t iRaw = Read_LTC2943_Register(REG_CURRENT_MSB);
  int16_t iOffset = iRaw - 32767;
  float LTCcurrent = (60.0 / RSENSE) * iOffset / 32767.0;
  return LTCcurrent;
}

float Request_Temp_LTC2943(){
    uint16_t tRaw = Read_LTC2943_Register(REG_TEMPERATURE_MSB);
  float tempK = 510.0 * tRaw / 65535.0;
  float tempC = tempK - 273.15;
  return tempC;
}

float Request_SoC_LTC2943(){
  // Accumulated Charge (SoC)
  uint16_t acr = Read_LTC2943_Register(REG_ACC_CHARGE_MSB);
  charge_mAh = (acr - 32767) * QLSB;


  //charge_mAh = 1000*(float)(acr*LTC2943_CHARGE_lsb*prescaler*50E-3)/(resistor*4096);
//
  return charge_mAh;
}

void setupLTC2943() {
  // Reset charge accumulator
  write_LTC2943_Register(REG_CONTROL, 0b11111001); // Set bit 0 to 1 to reset
  //delay(50);
  write_LTC2943_Register(REG_CONTROL, 0b11111000); // Re-enable analog section, auto mode, prescaler 4096
}


//////////////////////////////////////////////////////////////////////
//BQ Functions 
void CheckBQConnectionWithComms(){
if (!checkBQConnection()) {
    Serial.println("BQ25730 not responding on I2C. Check wiring or power.");
    while (1); // Halt system
  } else {
    Serial.println("BQ25730 connection verified.");
  }
}
void ConfigAndStartBQ(){
  // Configure initial charger settings
  setChargeVoltage(ChargeVoltageValue);
  setInputVoltage(inputVoltageValue);
  setChargeCurrent(chargeCurrentValue);
  setInputCurrentLimit(inputCurrentLimitValue);
  set_VSYS_MIN(VsysMinValue);
  enableADC();
  enableCharging();
}

// -----------------------------
// Register Read/Write Utilities
// -----------------------------

void writeBQ25730(uint8_t regAddr, uint16_t data) {
  Wire.beginTransmission(BQ25730_ADDR);
  Wire.write(regAddr);
  Wire.write(data & 0xFF);          // Low byte
  Wire.write((data >> 8) & 0xFF);   // High byte
  Wire.endTransmission();
  //delay(50);
}

uint16_t readBQ25730(uint8_t regAddr) {
  Wire.beginTransmission(BQ25730_ADDR);
  Wire.write(regAddr);
  Wire.endTransmission(false);
  Wire.requestFrom(BQ25730_ADDR, 2);
  uint16_t data = 0;
  if (Wire.available() == 2) {
    data = Wire.read();
    data |= Wire.read() << 8;
  }
  return data;
}

bool checkI2C() {
  uint16_t id = readBQ25730(DEVICE_ID);
  return (id != 0x0000 && id != 0xFFFF);
}

bool checkBQConnection() {
  Wire.beginTransmission(BQ25730_ADDR);
  return (Wire.endTransmission() == 0);
}

// -----------------------------
// Charger Configuration
// -----------------------------

void disableVSYS() {
  Serial.println("------------- VSYS HAS BEEN DISABLED BECAUSE OF LOW BATTERY -----------------");

    // Step 1: Ensure OTG is disabled
    uint16_t chargeOption0 = readBQ25730(0x12);
    chargeOption0 &= ~(1 << 5);  // Clear EN_OTG bit
    writeBQ25730(0x12, chargeOption0);

    // Step 2: Ensure BATFETOFF_HIZ is cleared
    uint16_t chargeOption3 = readBQ25730(0x34);
    chargeOption3 &= ~(1 << 1);  // Clear BATFETOFF_HIZ
    writeBQ25730(0x34, chargeOption3);

    // Step 3: Force BATFET off
    chargeOption3 |= (1 << 7);   // Set BATFET_ENZ bit
    writeBQ25730(0x34, chargeOption3);

    // Step 4: Confirm
    chargeOption3 = readBQ25730(0x34);
    Serial.print("ChargeOption3 after BATFET_ENZ set: ");
    Serial.println(chargeOption3, HEX);

}


void setChargeVoltage(float voltage_V) {
  if (voltage_V < 1.024 || voltage_V > 23.000) {
    Serial.println("Charge voltage out of range (1.024V – 23.000V).");
    return;
  }

  uint16_t stepCount = static_cast<uint16_t>(voltage_V / 0.008 + 0.5);
  uint16_t encoded = (stepCount & 0x1FFF) << 3;

  //delay(50);
  Serial.print("Writing 0x"); Serial.print(encoded, HEX);
  Serial.print(" to ChargeVoltage ("); Serial.print(voltage_V); Serial.println(" V)");
  writeBQ25730(ChargeVoltage, encoded);
}

void setChargeCurrent(float current_A) {
  if (current_A < 0.0 || current_A > 16.256) {
    Serial.println("Charge current out of range (0 – 16.256 A).");
    return;
  }

  uint16_t stepCount = static_cast<uint16_t>(current_A / 0.128 + 0.5);
  uint16_t encoded = (stepCount << 6) & 0x1FC0;

  //delay(50);
  Serial.print("Writing 0x"); Serial.print(encoded, HEX);
  Serial.print(" to ChargeCurrent Register ("); Serial.print(current_A); Serial.println(" A)");
  writeBQ25730(ChargeCurrent, encoded);
  Serial.println("");
}

void setInputCurrentLimit(float current_mA) {
  if (current_mA < 50.0f) current_mA = 50.0f;
  if (current_mA > 6350.0f) current_mA = 6350.0f;

  uint16_t code = static_cast<uint16_t>(current_mA / 50.0f);
  uint16_t regValue = (code << 8) & 0x7F00;

  //delay(50);
  Serial.print("Writing 0x"); Serial.print(regValue, HEX);
  Serial.print(" to IIN_HOST Register ("); Serial.print(current_mA); Serial.println(" mA)");
  writeBQ25730(IIN_HOST, regValue);
}

void setInputVoltage(float voltage_V) {
  if (voltage_V < 3.2 || voltage_V > 23.0) {
    Serial.println("Input voltage out of range (3.2V – 23.0V).");
    return;
  }

  uint16_t stepCount = static_cast<uint16_t>((voltage_V - 3.2) / 0.064 + 0.5);
  uint16_t encoded = (stepCount << 6) & 0x3FC0;

  //delay(50);
  Serial.print("Writing 0x"); Serial.print(encoded, HEX);
  Serial.print(" to InputVoltage Register ("); Serial.print(voltage_V); Serial.println(" V)");
  writeBQ25730(InputVoltage, encoded);
}

void set_VSYS_MIN(float voltage_V) {
  if (voltage_V < 1.0 || voltage_V > 23.0) {
    Serial.println("VSYS_MIN voltage out of range (1.0V – 23.0V).");
    return;
  }

  uint16_t encoded = static_cast<uint16_t>(voltage_V * 10) << 8;

  //delay(50);
  Serial.print("Writing 0x"); Serial.print(encoded, HEX);
  Serial.print(" to VSYS_MIN ("); Serial.print(voltage_V); Serial.println(" V)");
  writeBQ25730(VSYS_MIN, encoded);
}

void enableCharging() {
  // 0xE70E: disables watchdog and enables charging permanently
  writeBQ25730(ChargeOption0, 0xE70E);
}

void disableCharging() {
  uint16_t option0 = readBQ25730(ChargeOption0);
  //option0 &= ~(1 << 0); // Clear CHRG_INHIBIT bit
  writeBQ25730(ChargeOption0, 0xE70F);
}

void enableADC() {
  writeBQ25730(ADCOption, 0x40FF);
  //delay(50);
}

// -----------------------------
// Data Readouts
// -----------------------------

void readBatteryCurrent() {
  uint16_t raw = readBQ25730(ADCIBAT);

  // Bits [0:6]: 7-bit discharge current @ 512 mA/LSB
  uint8_t dischargeCode = raw & 0x7F;
  float dischargeCurrent_mA = dischargeCode * 512.0f;

  // Bits [8:14]: 7-bit charge current @ 128 mA/LSB
  uint8_t chargeCode = (raw >> 8) & 0x7F;
  float chargeCurrent_mA = chargeCode * 128.0f;

  Serial.print("Battery Discharge Current: ");
  Serial.print(dischargeCurrent_mA);
  Serial.print(" mA, Charge Current: ");
  Serial.print(chargeCurrent_mA);
  Serial.println(" mA");
}

// -----------------------------
// Debug Utility
// -----------------------------

void dumpAllBQRegisters() {
  for (uint8_t addr = 0x00; addr <= 0x3E; addr += 2) {
    uint16_t value = readBQ25730(addr);
    Serial.print("Reg 0x");
    if (addr < 0x10) Serial.print("0");
    Serial.print(addr, HEX);
    Serial.print(" = 0x");
    if (value < 0x1000) Serial.print("0");
    if (value < 0x0100) Serial.print("0");
    if (value < 0x0010) Serial.print("0");
    Serial.println(value, HEX);
  }
}

//Write to charge register to stop failsafe from lack of comms
void MaintainChargingBQ(){
  // Periodically check I2C communication
  if (millis() - lastCheck1 > I2CcheckInterval) {
    lastCheck1 = millis();
    if (!checkI2C()) {
      Serial.println("I2C comms lost. Attempting to reinitialize...");
      Wire.end();
      //delay(50);
      Wire.begin();
      //delay(50);
    }
  }

  // Periodically re-write voltage/current registers to maintain charging
  if (millis() - lastCheck2 > registerUpdateInterval) {
    lastCheck2 = millis();
    setChargeVoltage(ChargeVoltageValue);
    setChargeCurrent(chargeCurrentValue);
    //dumpAllRegisters();
  }
  
}


//INA Functions
//Check if ina219s are connected
void CheckIfINAConnected()
{
   if (!ina219_0x40.begin()) {
    Serial.println("Couldn't find ina219 at 0x40");
    while (1);
  }
  if (!ina219_0x41.begin()) {
    Serial.println("Couldn't find ina219 at 0x41");
    while (1);
  }
  if (!ina219_0x44.begin()) {
    Serial.println("Couldn't find ina219 at 0x44");
    while (1);
  }
  /*
  if (!ina219_0x45.begin(0x45)) {
    Serial.println("Couldn't find ina219 at 0x45");
    while (1);
  } */
}

//Enables GPIO pins for balancer, CHGOK, LEDS, 
void EnableGPIOPins(){
  //Balancer bypass GPIO bank
  //Cell 1 Balance
  pinMode(PB1, OUTPUT);
  //Cell 2 Balance
  pinMode(PB0, OUTPUT);
  //Cell 3 Balance
  pinMode(PA7, OUTPUT);
  //Cell 4 Balance
  pinMode(PA6, OUTPUT);
  //CHG_OK
  pinMode(PA1, INPUT);

  //LED bank
  //PowerPlugInsertedLED
  pinMode(PB15, OUTPUT);//28
  //ChargeLED
  pinMode(PB14, OUTPUT);//27
  //BMS_ERROR_LED
  pinMode(PB13, OUTPUT);//26
  //BMS_STATUS_LED
  pinMode(PB12, OUTPUT);//25

  //Thermister bank
  //Thermister  1
  pinMode(PA2,INPUT);
  //Thermister  2
  pinMode(PA3,INPUT);
  //Thermister  3
  pinMode(PA4,INPUT);
  //Thermister  4
  pinMode(PA5,INPUT);
}
// Call this each loop to automatically stop charging if any cell exceeds charge or discharge conditions

void checkCellandSocCutoff() { 
  //Serial.print("\n\n\nMade it into voltage calcs");
  // Gather which cells are over the hard cutoff
  bool anyOverCutoff = false;
  String overList = "";
  if (CELL1_VOLTAGE_LTC2943 >= CellMaxCutOffV) { anyOverCutoff = true; overList += "1 "; }
  if (CELL2_VOLTAGE         >= CellMaxCutOffV) { anyOverCutoff = true; overList += "2 "; }
  if (CELL3_VOLTAGE         >= CellMaxCutOffV) { anyOverCutoff = true; overList += "3 "; }
  if (CELL4_VOLTAGE         >= CellMaxCutOffV) { anyOverCutoff = true; overList += "4 "; }

// Gather which cells are under the hard cutoff
  bool anyUnderCutoff = false;
  String underList = "";
  if (CELL1_VOLTAGE_LTC2943 <= CellMinCutOffV) { anyUnderCutoff = true; underList += "1 "; }
  if (CELL2_VOLTAGE         <= CellMinCutOffV) { anyUnderCutoff = true; underList += "2 "; }
  if (CELL3_VOLTAGE         <= CellMinCutOffV) { anyUnderCutoff = true; underList += "3 "; }
  if (CELL4_VOLTAGE         <= CellMinCutOffV) { anyUnderCutoff = true; underList += "4 "; }

  // Check if *all* cells are above the balancing voltage (CellFullChargeV)
  bool allAboveMax =
       (CELL1_VOLTAGE_LTC2943 >= CellFullChargeV) &&
       (CELL2_VOLTAGE         >= CellFullChargeV) &&
       (CELL3_VOLTAGE         >= CellFullChargeV) &&
       (CELL4_VOLTAGE         >= CellFullChargeV);

  
  charge_mAh = Request_SoC_LTC2943();
  //Adjust Charge to compensate for how LTC tracks Coulombs
  real_charge_mAh = charge_mAh+Pack_stock_capacity;

  //Any cell charged over CellMaxCutOffV stop charging
  if (anyOverCutoff && CHARGING) {
    disableCharging();
    CHARGING = false;
    Serial.println(F("\n=== CHARGING STOPPED: HARD OV CUTOFF ==="));
    Serial.print  (F("Cells over cutoff ("));
    Serial.print  (CellMaxCutOffV, 3);
    Serial.print  (F(" V): "));
    Serial.println(overList);  
    Serial.println(F("===========================================\n"));
  }

  //Any cell falls under anyUnderCutoff stop discharging
  if (anyUnderCutoff) {
    //STOPDISCHARGING();
    Serial.println(F("\n=== DISCHARGING STOPPED: HARD UV CUTOFF ==="));
    Serial.print  (F("Cells under cutoff ("));
    Serial.print  (CellMinCutOffV, 2);
    Serial.print  (F(" V): "));
    Serial.println(underList);  
    Serial.println(F("=============================================\n"));
    
  }

  // All cells charged stop charing
   if (allAboveMax && CHARGING) {
    disableCharging();
    CHARGING = false;
    Serial.println(F("\n=== CHARGING STOPPED: ALL CELLS ABOVE CellFullChargeVolt ==="));
    Serial.print  (F("All cells ≥ "));
    Serial.print  (CellFullChargeV, 2);
    Serial.println(F(" V"));
    Serial.println(F("=============================================================\n"));
  }

  //SoC says pack is charged stop charging
  if (real_charge_mAh >= Pack_stock_capacity) {
    disableCharging();
    CHARGING = false;
    Serial.println(F("\n=== CHARGING STOPPED: Pack is Fully Charged (SoC) ==="));
    Serial.print  (F("Pack at:"));
    Serial.print  (real_charge_mAh);
    Serial.println(F(" mAh"));
    Serial.println(F("=======================================================\n"));
  }

  //Disable DisCharging if SoC is empty
  if (real_charge_mAh <= 0 && CHARGING == false) {
    //STOPDISCHARGING();
    Serial.println(F("\n=== DISCHARGING STOPPED: Pack is EMPTY (SoC) ==="));
    Serial.print  (F("Pack at:"));
    Serial.print  (real_charge_mAh);
    Serial.println(F(" mAh"));
    Serial.println(F("============================================\n"));
    //disableVSYS();
    
  }
}
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
void loop() {
  //ChargeLED
  digitalWrite(PB14, HIGH);

  __asm__("nop");
}
//EOF

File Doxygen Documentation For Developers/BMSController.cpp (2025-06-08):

/**
 * @file BMSController.cpp
 * @brief Implementation of BMSController class for I2C communication with Battery Management System
 * @author Your Name
 * @date Current Date
 * @version 1.0
 * 
 * This file implements the BMSController class which provides a high-level interface
 * for communicating with a Battery Management System (BMS) over I2C. The class
 * handles configuration parameters, sensor readings, and State of Charge calculations.
 */

#include "BMSController.h"

/** @brief Global variable to store the given State of Charge capacity for percentage calculations */
float SoCGiven;

/**
 * @brief Constructor for BMSController class
 * 
 * Initializes the BMSController with the specified I2C address and sets up
 * the I2C communication interface.
 * 
 * @param i2cAddress I2C slave address of the BMS device (7-bit address)
 * 
 * @note Wire.begin() is called during construction to initialize I2C
 */
BMSController::BMSController(uint8_t i2cAddress) {
  _address = i2cAddress;
  Wire.begin();
}

/**
 * @brief Initialize communication with the BMS device
 * 
 * Tests communication with the BMS by attempting to establish an I2C connection.
 * This function should be called after construction to verify the device is
 * responding on the specified address.
 * 
 * @return true if BMS device responds to I2C communication
 * @return false if no response from BMS device
 * 
 * @note This function reinitializes Wire.begin() for safety
 */
bool BMSController::begin() {
  Wire.begin();
  Wire.beginTransmission(_address);
  if (Wire.endTransmission() == 0) {
    return true;  // Device responded
  }
  return false;  // No response
}

/**
 * @brief Send a float value with command to BMS (Legacy version - commented out)
 * 
 * Basic implementation without retry logic or error handling.
 * This version has been replaced by the experimental version below.
 * 
 * @param command Command byte to send to BMS
 * @param value Float value to transmit
 */
/**void BMSController::sendFloat(uint8_t command, float value) {
  Wire.beginTransmission(_address);
  Wire.write(command);
  uint8_t buf[4];
  memcpy(buf, &value, sizeof(float));
  Wire.write(buf, 4);
  Wire.endTransmission();
}**/

///////////////////////////////////EXPERIMENTAL/////////////////////////////////////////////////

/**
 * @brief Send a float value with command to BMS (Enhanced version with retry logic)
 * 
 * This experimental version includes robust error handling with automatic retry
 * capability to handle I2C bus congestion or temporary communication failures.
 * The function will retry up to 10 times with 5ms delays between attempts.
 * 
 * @param command Command byte to send to BMS (see command reference)
 * @param value Float value to transmit (4-byte IEEE 754 format)
 * 
 * @note Maximum 10 retries with 5ms delay between attempts
 * @note Prints error message to Serial if all retries fail
 * @warning Function blocks during retry attempts
 * 
 * @details Command format: [command_byte][4_bytes_float_data]
 * Total transmission: 5 bytes
 */
void BMSController::sendFloat(uint8_t command, float value) {
  const uint8_t maxRetries = 10;
  const uint16_t retryDelayMs = 5;
  uint8_t retries = 0;
  int transmissionResult = 4; // Arbitrary non-zero value to enter loop
  
  // Retry loop to wait for the bus to become available
  while (retries < maxRetries) {
    Wire.beginTransmission(_address);
    Wire.write(command);
    uint8_t buf[4];
    memcpy(buf, &value, sizeof(float));
    Wire.write(buf, 4);
    transmissionResult = Wire.endTransmission();
    
    if (transmissionResult == 0) {
      // Success
      break;
    } else {
      // Transmission failed, possibly bus busy or NACKed
      retries++;
      delay(retryDelayMs);
    }
  }
  
  if (transmissionResult != 0) {
    // Optional: handle error here (e.g., log or raise flag)
    Serial.print("I2C transmission failed, error code: ");
    Serial.println(transmissionResult);
  }
}

////////////////////////////////////////////////////////////////////////////////

/**
 * @brief Set the charge voltage limit for the battery pack
 * 
 * Configures the maximum voltage that the battery pack should be charged to.
 * This is a critical safety parameter that prevents overcharging.
 * 
 * @param volts Charge voltage limit in volts
 * @return true if command was sent successfully
 * @return false if transmission failed
 * 
 * @note Command code: 0x10
 * @warning Ensure voltage is within safe limits for your battery chemistry
 */
bool BMSController::setChargeVoltage(float volts) {
  sendFloat(0x10, volts);
  return true;
}

/**
 * @brief Set the minimum system voltage threshold
 * 
 * Configures the minimum voltage below which the system should take
 * protective action to prevent deep discharge damage.
 * 
 * @param volts Minimum system voltage in volts
 * @return true if command was sent successfully
 * @return false if transmission failed
 * 
 * @note Command code: 0x11
 */
bool BMSController::setVsysMin(float volts) {
  sendFloat(0x11, volts);
  return true;
}

/**
 * @brief Set the input voltage limit for charging
 * 
 * Configures the maximum input voltage that the charging system will accept.
 * This helps protect against overvoltage conditions from the power supply.
 * 
 * @param volts Input voltage limit in volts
 * @return true if command was sent successfully
 * @return false if transmission failed
 * 
 * @note Command code: 0x13
 */
bool BMSController::setInputVoltageLimit(float volts) {
  sendFloat(0x13, volts);
  return true;
}

/**
 * @brief Set the maximum charge current limit
 * 
 * Configures the maximum current that should be used during charging.
 * This parameter is crucial for battery safety and longevity.
 * 
 * @param amps Maximum charge current in amperes
 * @return true if command was sent successfully
 * @return false if transmission failed
 * 
 * @note Command code: 0x14
 * @warning Ensure current is within battery specifications
 */
bool BMSController::setChargeCurrent(float amps) {
  sendFloat(0x14, amps);
  return true;
}

/**
 * @brief Set the input current limit from power supply
 * 
 * Configures the maximum current that can be drawn from the input power supply.
 * This prevents overloading the power source during charging.
 * 
 * @param milliamps Input current limit in milliamperes
 * @return true if command was sent successfully
 * @return false if transmission failed
 * 
 * @note Command code: 0x15
 * @note Parameter is in milliamperes, not amperes
 */
bool BMSController::setInputCurrentLimit(float milliamps) {
  sendFloat(0x15, milliamps);
  return true;
}
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

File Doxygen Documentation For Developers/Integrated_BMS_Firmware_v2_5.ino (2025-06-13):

//Integrated BMS Firmware V2_3 //Sodium & Lithium ION BMS //Include wire for I2C #include <Wire.h> //Includes for INA #include <Adafruit_INA219.h> //include for interrupts #include <HardwareSerial.h> #include <STM32TimerInterrupt.h> #include "stm32f1xx.h" #include <EEPROM.h> //EEPROM


/**
 * @file BMS_Firmware_V2_3.ino
 * @brief Integrated Battery Management System Firmware Version 2.3
 * @details Supports both Sodium and Lithium Ion battery chemistries with comprehensive monitoring and protection
 * @version 2.3
 * @date 2024
 * @author BMS Development Team
 */

//! Integrated BMS Firmware V2_3
//! Sodium & Lithium ION BMS

//! Include Wire library for I2C communication
#include <Wire.h>
//! Include Adafruit INA219 current/voltage sensor library
#include <Adafruit_INA219.h>
//! Include hardware serial library for interrupt handling
#include <HardwareSerial.h>
//! Include STM32 timer interrupt library for periodic tasks
#include <STM32TimerInterrupt.h>
//! Include STM32 hardware abstraction layer
#include "stm32f1xx.h"
//! Include EEPROM library for persistent storage
#include <EEPROM.h>

/**
 * @defgroup EEPROM_Storage EEPROM Storage Addresses
 * @brief EEPROM storage locations for system initialization values passed by controller MCU
 * @{
 */
#define EEPROM_ADDR_1  0                                       //!< EEPROM address for float value 1 (ChargeVoltageValue)
#define EEPROM_ADDR_2  (EEPROM_ADDR_1 + (2*sizeof(float)))     //!< EEPROM address for float value 2 (VsysMinValue)
#define EEPROM_ADDR_3  (EEPROM_ADDR_2 + (2*sizeof(float)))     //!< EEPROM address for float value 3 (inputVoltageValue)
#define EEPROM_ADDR_4  (EEPROM_ADDR_3 + (2*sizeof(float)))     //!< EEPROM address for float value 4 (chargeCurrentValue)
#define EEPROM_ADDR_5  (EEPROM_ADDR_4 + (2*sizeof(float)))     //!< EEPROM address for float value 5 (inputCurrentLimitValue)
#define EEPROM_ADDR_6  (EEPROM_ADDR_5 + (2*sizeof(float)))     //!< EEPROM address for float value 6 (CellMaxCutOffV)
#define EEPROM_ADDR_7  (EEPROM_ADDR_6 + (2*sizeof(float)))     //!< EEPROM address for float value 7 (CellMinCutOffV)
#define EEPROM_ADDR_8  (EEPROM_ADDR_7 + (2*sizeof(float)))     //!< EEPROM address for float value 8 (Pack_stock_capacity)
#define EEPROM_ADDR_9  (EEPROM_ADDR_8 + (2*sizeof(float)))     //!< EEPROM address for float value 9 (EEPROM_CONFIG_FLAG)
#define EEPROM_TOTAL_LENGTH (9 * (2*sizeof(float)))            //!< Total EEPROM length for 9 float values
/** @} */

////////////////////////////////////////////////////////////////
/**
 * @defgroup INA219_Instances INA219 Sensor Instances
 * @brief Create instances for each ina219 sensor
 * @{
 */
Adafruit_INA219 ina219_0x40(0x40); //!< INA219 sensor instance at I2C address 0x40
Adafruit_INA219 ina219_0x41(0x41); //!< INA219 sensor instance at I2C address 0x41
Adafruit_INA219 ina219_0x44(0x44); //!< INA219 sensor instance at I2C address 0x44
/** @} */

/**
 * @defgroup System_Flags Major System Control Flags
 * @brief Global flags controlling major system operations
 * @{
 */
volatile bool CHARGING = false;             //!< Flag indicating if charging is currently active
String serialCmdBuffer = "";               //!< Buffer for accumulating incoming serial characters for charge control
volatile bool CHARGE_ON_PLUGIN = true;     //!< When true, charging auto-starts on charger plugin detection
volatile bool STOPCHARGING = false;        //!< Flag to request charging stop
volatile bool KILLLOAD = false;            //!< Flag to disconnect load
volatile bool PLUGGEDIN = false;           //!< Flag indicating charger is physically connected
volatile bool OVERHEAT = false;            //!< Flag indicating thermal protection activation
volatile bool ERRORFLG = false;            //!< General error flag for system faults
/** @} */

/**
 * @defgroup Timer_Flags Timer and Configuration Flags
 * @brief Flags related to timing and system configuration
 * @{
 */
volatile bool EEPROM_LOADED = false;       //!< Flag indicating EEPROM data has been loaded
float EEPROM_CONFIG_FLAG;                  //!< Configuration flag stored in EEPROM
volatile bool CONFIGURED = false;          //!< Flag indicating system is fully configured
/** @} */

int configstatus = 0;                      //!< Configuration status counter (0-8)
int ConfigStatusFromMaster;                //!< Configuration status received from master controller

//! Timer instance using TIM2 for periodic system checks
STM32Timer ITimer2(TIM2);

/**
 * @brief Timer interrupt service routine
 * @details Called periodically to set flags for sensor and serial updates
 * @note Currently contains only a test placeholder
 */
void onTimerISR() {
  //TEST_FLAG = true;  //!< Placeholder for future timer-based operations
}

/**
 * @defgroup INA_BQ_Variables INA219 and BQ25730 Variables
 * @brief Variables for storing sensor readings and measurements
 * @{
 */
float INA_0x40_VOLTAGE = 0.0;              //!< Voltage reading from INA219 at address 0x40
float INA_0x41_VOLTAGE = 0.0;              //!< Voltage reading from INA219 at address 0x41
float INA_0x44_VOLTAGE = 0.0;              //!< Voltage reading from INA219 at address 0x44
float CELL1_VOLTAGE_LTC2943 = 0.00;        //!< Cell 1 voltage calculated from LTC2943 readings
float CELL1_VOLTAGE = 0.00;                //!< Cell 1 voltage (alternative calculation)
float CELL2_VOLTAGE = 0.00;                //!< Cell 2 voltage calculated from INA differential readings
float CELL3_VOLTAGE = 0.00;                //!< Cell 3 voltage calculated from INA differential readings
float CELL4_VOLTAGE = 0.00;                //!< Cell 4 voltage (bottom cell in series stack)
/** @} */

//! Thermistor threshold value: 3.3V / 2 = 1.65V scaled to 12-bit ADC: (1.65 / 3.3) * 4095 ≈ 2047
const int THERMISTER_THRESHOLD = 2047;
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

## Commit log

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2025-04-10 Add files via upload
    This folder contains the singular components used for the BMS. Each component has its own folder that contains the following:
    * KiCAD 2D model
    * KiCAD Footprint
    [2N7002P_215.step, BQ25730RSNR.step, CM8V-T1A-32.768KHZ-12.5PF-20PPM-TA-QA.step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]
2025-04-11 BQ24z100 hard reset
    I think my Bq is dead so this is might be hot garbage;
    [BQ34_Reset_Driver.ino]
2025-04-11 Add files via upload
    This version of the driver is initializing the BQ25730 EVM board where the battery pack is being charged (VBAT) and the external load is being driven (VSYS)
    Issues: the charging stops after ~3 minutes
    The ChargeStatus register changes from 0c8400 to 0x8000 when charging starts, indicating Upper Byte [2] (IN_FCHRG) is flipping from a 1 to 0 n-> switching from Fast Charge to Not in Fast Charge
    [BQ25370_BMS_Driver.ino]
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2025-04-12 Add files via upload
    This file contains the 2nd iteration of the Schematic of our Battery Management System.
    [Battery Management System.kicad_pcb, Battery Management System.kicad_sch, Charge_Control.kicad_sch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]
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2025-04-21 Add files via upload
    Latest iteration of KiCAD schematic for Battery Management System
    [Battery Management System.kicad_pcb, Battery Management System.kicad_sch, Charge_Control.kicad_sch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]
2025-04-21 Pulled together root sheet so that it's obvious how the power flows and how the blocks are connected. Finally, a decent block diagram :)
    [Battery Management System.kicad_sch, Charge_Control.kicad_sch, Microcontroller.kicad_sch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]
2025-04-21 Renamed untitled to Cell Interface
    [Battery Management System.kicad_sch, Cell_Interface.kicad_sch]
2025-04-21 Remove spaces from filenames. I know, sorry.
    [Battery_Management_System.kicad_pcb, Battery_Management_System.kicad_sch]
2025-04-21 Kill all the unecessary folders.
    [Battery_Management_System.kicad_pcb, Battery_Management_System.kicad_sch, Cell_Interface.kicad_sch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]
2025-04-21 Yeah, it's not the schematics, it's really just KiCAD.
    [2N7002P_215.step, BQ25730RSNR.step, Battery_Management_System.kicad_pcb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]
2025-04-21 It's a board, not a schematics.
    [2N7002P_215.step, BQ25730RSNR.step, Battery_Management_System.kicad_pcb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]
2025-04-21 Added project libraries that were previously committed
    [Battery_Management_System.kicad_pcb, Battery_Management_System.kicad_sch]
2025-05-03 Updated Schematic & PCB Layout
    Updated the look of the PCB layout to make the power flow Vin more intuitive.
    @KeytarGoblin
    [Battery_Management_System.kicad_pcb, Charge_Control.kicad_sch, Microcontroller.kicad_sch]
2025-05-03 Completed PCB Layout
    fully placed all components within the bound of the first iteration of the PCB. We are good to start traceout @KeytarGoblin @andrewgreenberg
    [Battery_Management_System.kicad_pcb]
2025-05-05 updated version of PCB
    here's my latest update @KeytarGoblin @andrewgreenberg
    [Battery_Management_System.kicad_pcb, Charge_Control.kicad_sch, Microcontroller.kicad_sch]
2025-05-05 Schematic: - Fixed FDI plug - Added thermistor connectors - Added a bunch of NCs using KiCAD NC tool - Added filter cap back into battery current shunt - Added bypass cap to LTC - Removed Cell 4 INA2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
    [Battery_Management_System.kicad_pcb, Battery_Management_System.kicad_sch, Cell_Interface.kicad_sch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]
2025-05-05 Schematic: - Changed to smaller 4 pin crystal - Added STM32 bypass caps Layout: - Added some example zones around vbus - Initial component placement for STM32 - Did an example Kelvin connection for s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
    [Battery_Management_System.kicad_pcb, Battery_Management_System.kicad_sch, Microcontroller.kicad_sch]
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2025-05-07 New traces created
    Populated lower half of PCB with new traces. Left most of the high voltage traces unchanged. Need Eyes on this ASAP
    [2N7002P_215.step, BQ25730RSNR.step, Battery_Management_System.kicad_pcb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]
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2025-05-08 Completed PCB Traceout
    PCB Layout and traceout completed
    @KeytarGoblin @Danish2PSU @andrewgreenberg
    [Battery_Management_System.kicad_pcb, Cell_Interface.kicad_sch]
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2025-05-08 Updated board rules, AGAIN. WTF is going on?
    [Battery_Management_System.kicad_pcb]
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2025-05-08 Start work on 2nd version of LTC2943 driver
    main goal is to fix current scaling, eliminate vestigial code and modularize the driver for implementation into mainline
    [LTC2943_Driver_v0_2.ino]
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2025-05-09 Fixed current calculations
    Current calculations are good but voltage still floats
    [LTC2943_Driver_v0_3.ino]
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2025-05-09 Voltage and current fixed, Merged in BQ code to LTC code
    Merged LTC and BQ code
    SoC still having issues
    [LTC2943_and_BQ_Driver_v0_4.ino]
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2025-05-09 Fixed formatting issue in Git
    [LTC2943_Driver_v0_1.ino]
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2025-05-09 revised PCB
    This design accounts for majority of the updates requested by Faculty Advisor
    @KeytarGoblin @andrewgreenberg
    [Battery_Management_System.kicad_pcb, Cell_Interface.kicad_sch, Charge_Control.kicad_sch]
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2025-05-09 Team #6 - Battery Management Module Rev 1 - PCB
    [Battery_Management_System.kicad_pcb, Battery_Management_System.kicad_sch, Cell_Interface.kicad_sch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]
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2025-05-10 Fixed Library paths for component symbol
    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
    [Cell_Interface.kicad_sch, Charge_Control.kicad_sch, Microcontroller.kicad_sch]
2025-05-10 PCB Revision
    PCN near full completion, currently running on no errors while running DRC.
    @KeytarGoblin @andrewgreenberg @Danish2PSU
    [Battery_Management_System.kicad_pcb, Cell_Interface.kicad_sch, Charge_Control.kicad_sch]
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2025-05-10 Polish on schematic and board. Changed balance resistors to 100 ohms. Lots of silly OCD cleanup and documentation. Board has thicker (0.2mm) I2C lines, cleaned up 3.3V connections to reduce impedance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
    [Battery_Management_System.kicad_pcb, Battery_Management_System.kicad_sch, Cell_Interface.kicad_sch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]
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2025-05-10 Battery Management System Rev 1 Board
    Completed Rev 1 PCB board
    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
    [Battery_Management_System.kicad_pcb, Cell_Interface.kicad_sch]
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2025-05-11 Gerber Files update
    Updated gerber files based on edits made on current PCB
    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
    [Battery_Management_System.kicad_pcb]
2025-05-11 Added CHG_OK functionality
    Added CHG_OK functionality with error if no connection to power when a charge request is sent
    [Integrated_BMS_Driver_v1_2.ino]
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2025-05-17 PCB Optimization
    Made changes to the PCB to make it smaller, as well as adding the Castellated Vias
    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
    [Battery_Management_System.kicad_pcb, Battery_Management_System.kicad_sch, Charge_Control.kicad_sch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]
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2025-05-18 Optimized PCB
    PCB new dimensions:
    43 x 53 mm
    [Battery_Management_System.kicad_pcb, Battery_Management_System.kicad_sch]
2025-05-20 Fixed Track sizes
    [Battery_Management_System.kicad_pcb]
2025-05-20 Cleaned up BOM materials again. Why do these keep reseting? Also, big refactor on cell balancing circuits and battery connection (NOW FLIPPED) to make board smaller. More smallification is left as an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
    [Battery_Management_System.kicad_pcb, Battery_Management_System.kicad_sch, Cell_Interface.kicad_sch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]
2025-05-20 Oh, look, we can save another few mm.
    [Battery_Management_System.kicad_pcb]
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2025-05-23 Breakout Board updated
    Added ground zones, fixed issues with malformed board
    [Breakout Board for BMS.kicad_pcb]
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2025-05-24 Revision to the board
    @andrewgreenberg added ground vias near the components needing ground
    [Battery_Management_System.kicad_pcb, Battery_Management_System.kicad_sch]
2025-05-24 Fixed voltage calls, moved LTC stuff to Balance()
    [Integrated_BMS_Firmware_v2_0.ino]
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2025-05-26 Breakout Rev1 is Ready.
    No Errors on DRC, ready to be sent to FAB
    [Battery_Management_System.kicad_pcb, Breakout Board for BMS.kicad_pcb]
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2025-05-30 Update Integrated_BMS_Firmware_v2_1.ino
    Fixed timer issue
    [Integrated_BMS_Firmware_v2_1.ino]
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2025-06-04 DNW
    Does not work.
    But... slightly better
    [BMSController.cpp, Flash_Storage_Test_STM32_v1.ino, Integrated_BMS_Firmware_v2_2.ino]
2025-06-07 Working Version
    Removed all delays in FW version 2.3
    Added SoC to end user library
    Added i2c error handling to end user library
    [BMSController.cpp, ESP32_BMS_Controller_Library_Test_v2.ino, Integrated_BMS_Firmware_v2_3.ino]
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
